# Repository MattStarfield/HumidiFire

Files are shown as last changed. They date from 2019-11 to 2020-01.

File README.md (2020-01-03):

# HumidiFire
A water vapor based fireplace simulator



### Table of Contents
* [Documentation](#Documentation)
* [Hardware](#Hardware)
* [Firmware](#Firmware)
* [Software](#Software)
---

## Documentation

## Hardware
* [Bill of Materials](https://docs.google.com/spreadsheets/d/1JZTtaZDqRExDhAQ4nWuzvwM8wr-2eBfdn1ZWpzmeVy4/edit#gid=0)

## Firmware

## Software

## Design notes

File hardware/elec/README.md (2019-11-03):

### Hardware > Electrical Design
Contains PCB and electronics design files including:

Eagle CAD Project files:
- [ ] Schematic `.sch`
- [ ] PCB Layout `.brd`
- [ ] Library Components `.lbr`
- [ ] Eagle Project File `eagle.epf`

Exported files:
- [ ] Schematic PDF `.pdf`
- [ ] PCB image Render `.png`
- [ ] Gerber files `.zip`

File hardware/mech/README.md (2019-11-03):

### Hardware > Mechanical Design
Contains 2D, 3D CAD and mechanical design files including:

 Adobe Illustrator files:
- [ ] Laser Cut & Engrave files `.ai`

Fusion 360 files:
- [ ]

Exported files:
- [ ] 2D Laser PDF `.pdf`
- [ ] PCB Dimension Outline `.dxf`

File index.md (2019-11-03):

# Project Site
A brief description of the project's function and purpose

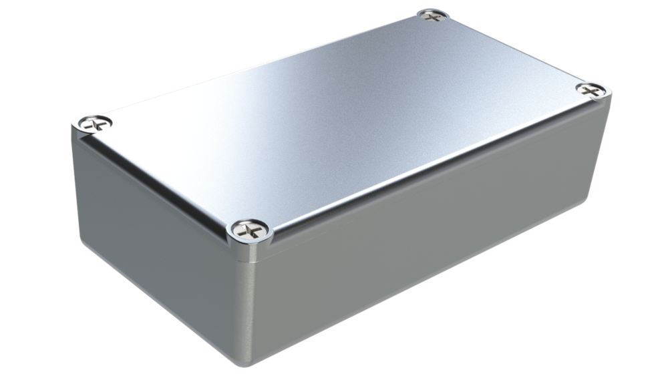
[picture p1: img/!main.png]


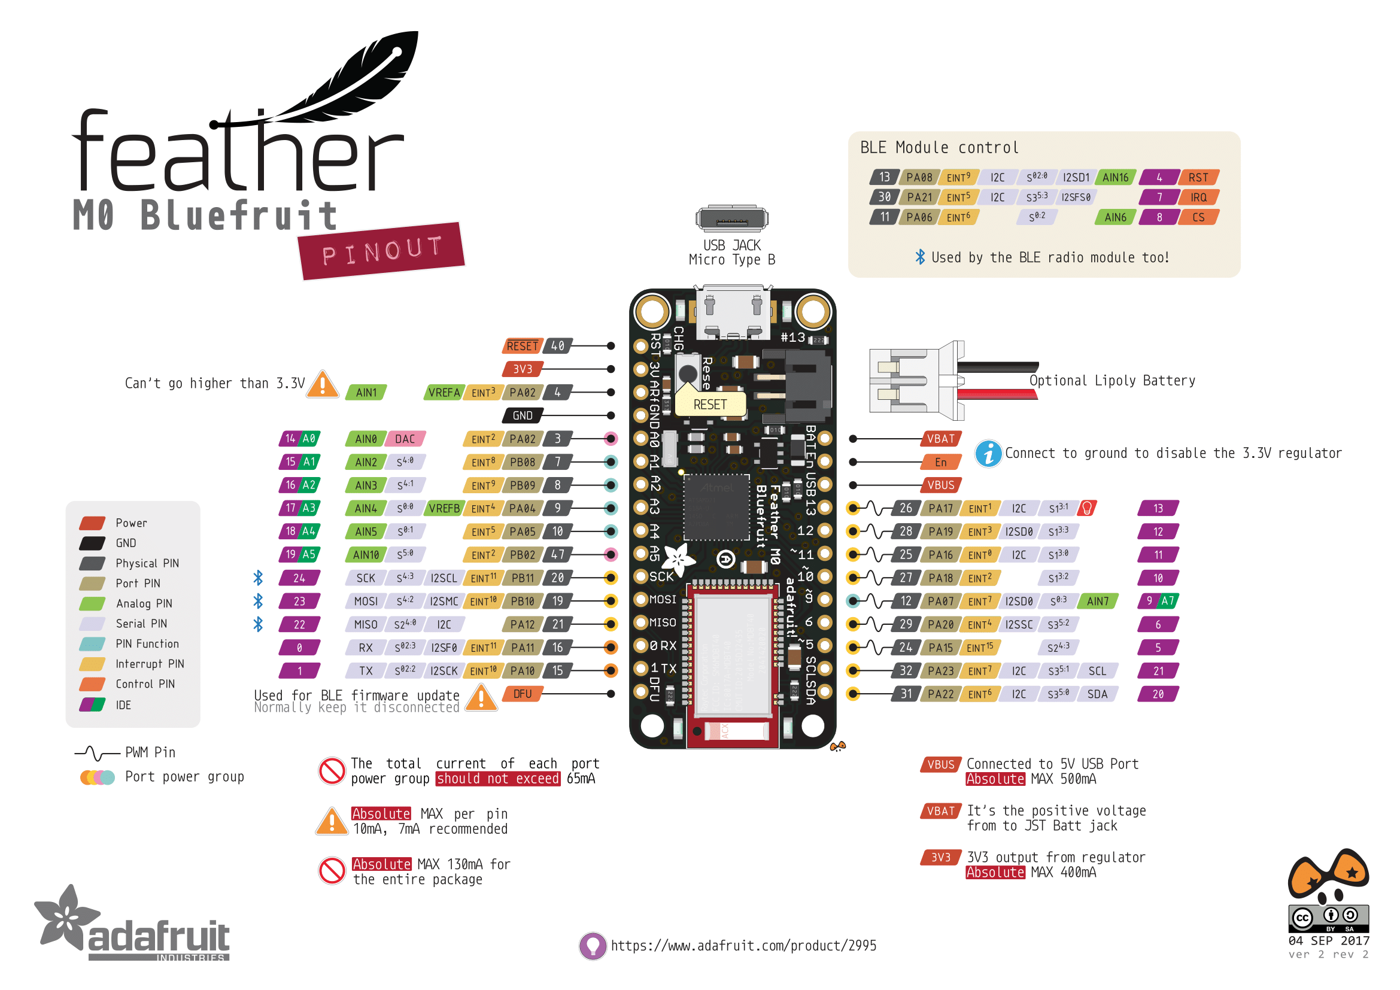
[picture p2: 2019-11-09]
img/feather-m0-pinout.png

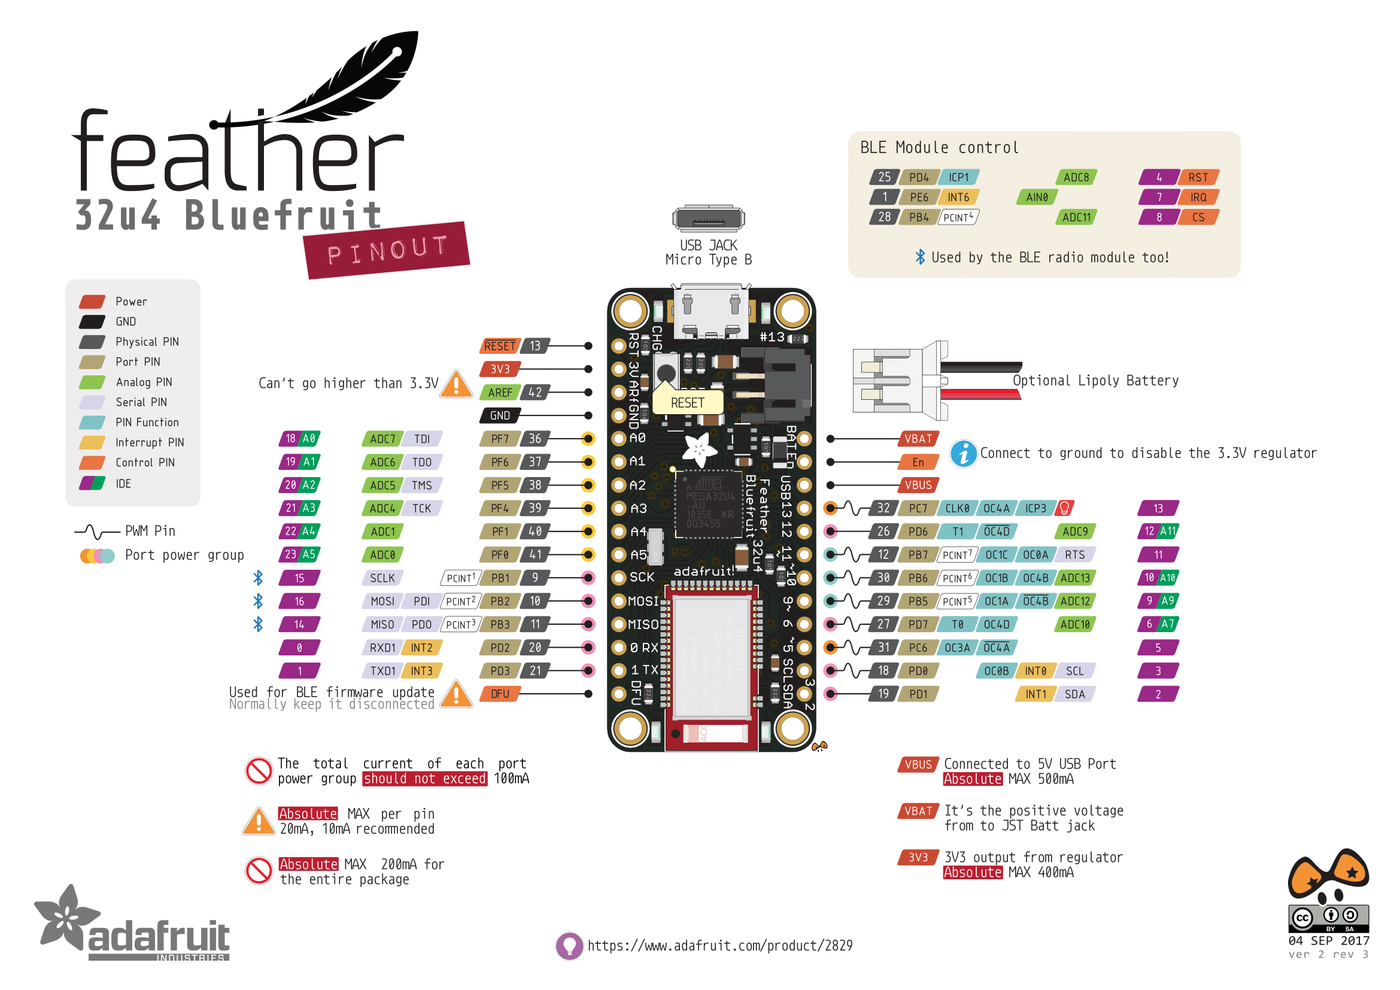
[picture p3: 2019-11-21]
img/feather-32u4-pinout.png

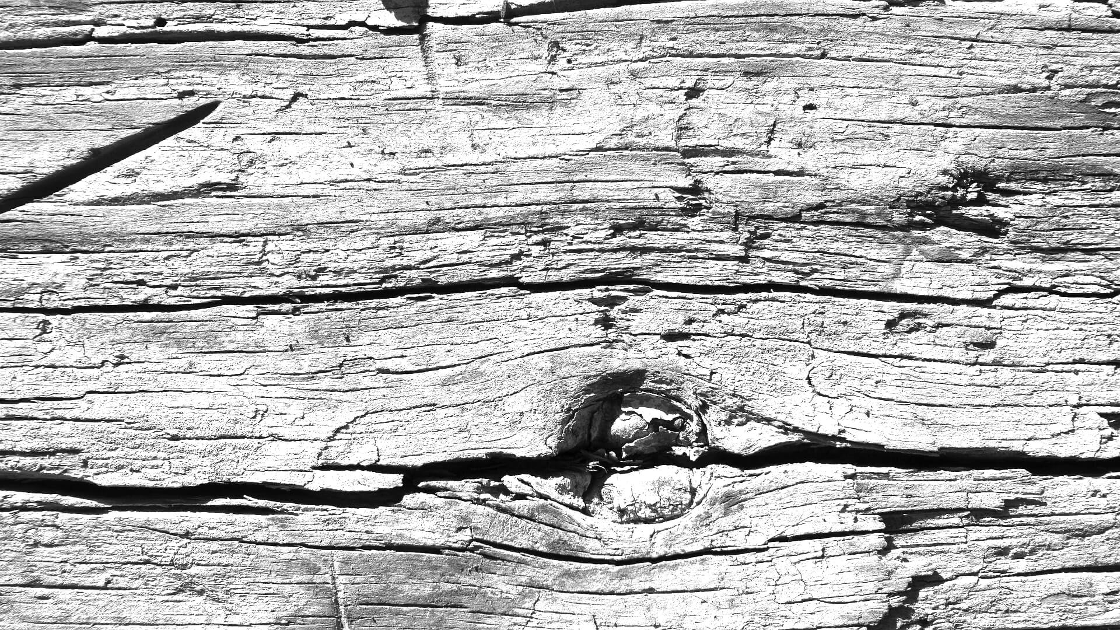
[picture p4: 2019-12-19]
hardware/mech/woodgrain-texture9.jpg

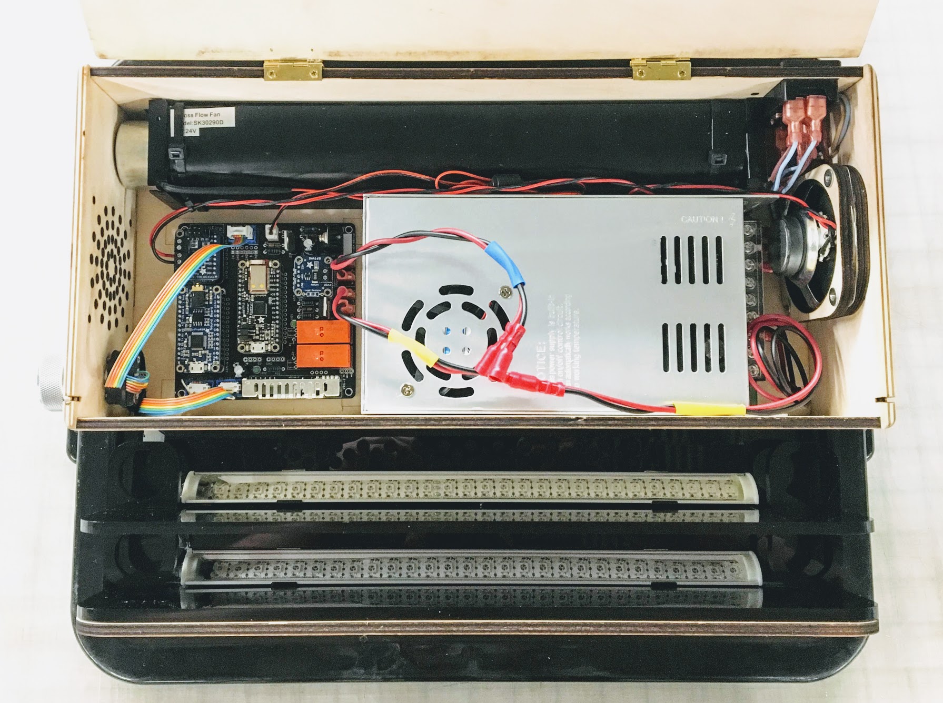
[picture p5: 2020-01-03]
img/hw07.jpg

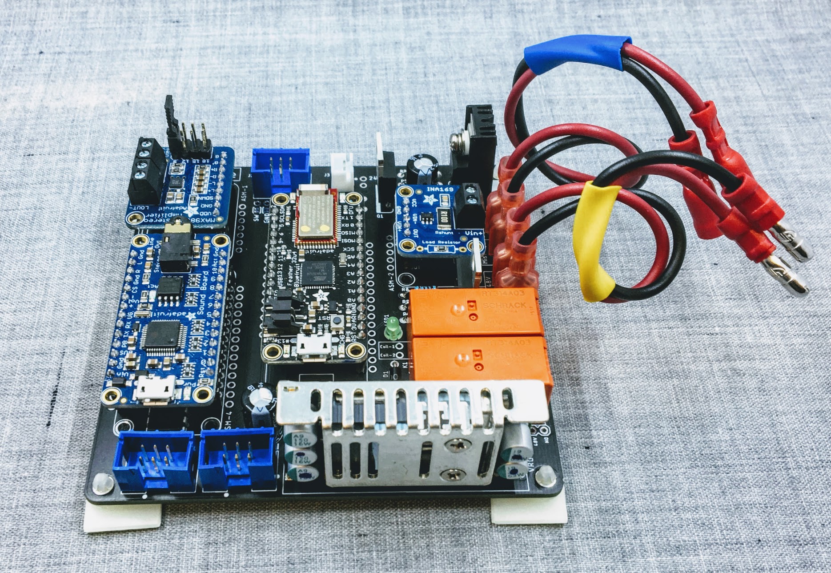
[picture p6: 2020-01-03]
img/pcb04.jpg

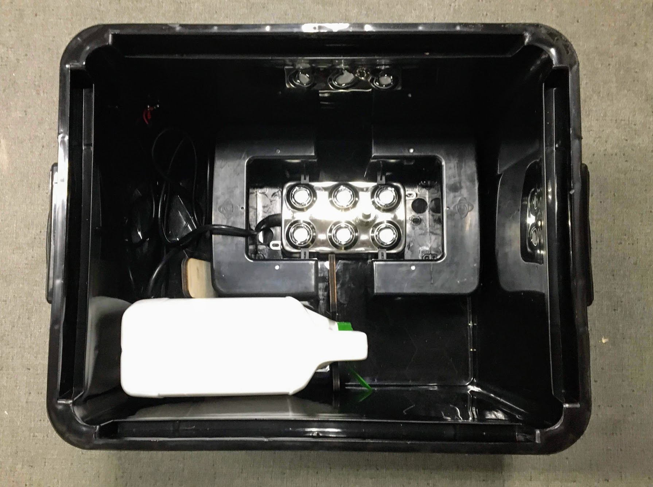
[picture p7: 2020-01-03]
img/hw08.jpg

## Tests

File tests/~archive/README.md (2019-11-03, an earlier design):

### Archive
Contains files that are no longer necessary in the formal project, but may be useful to keep for future reference.

---
_Note: Keep this `README.md` file in place to ensure this folder is included in the Git project structure when the folder is empty_

_Note: `~` is used to place folder at the bottom of file system sorting order_

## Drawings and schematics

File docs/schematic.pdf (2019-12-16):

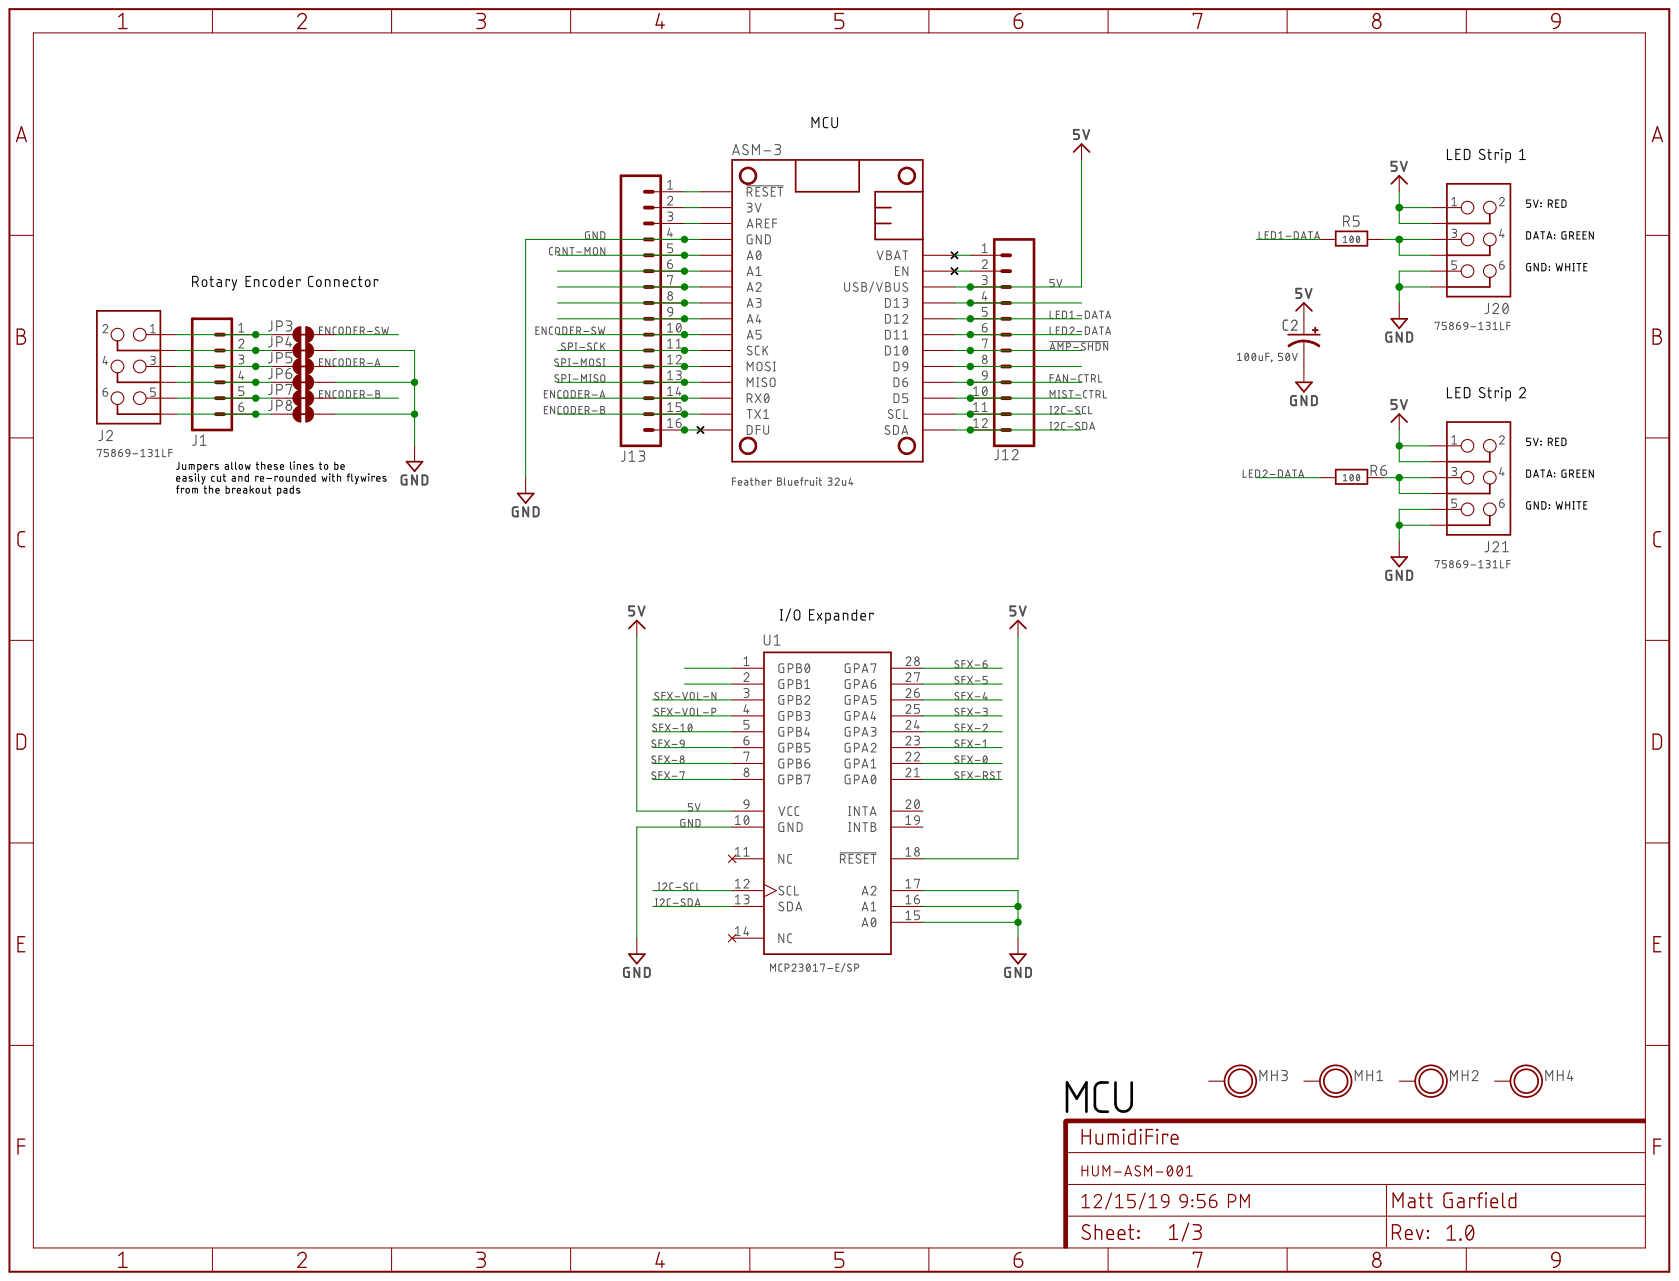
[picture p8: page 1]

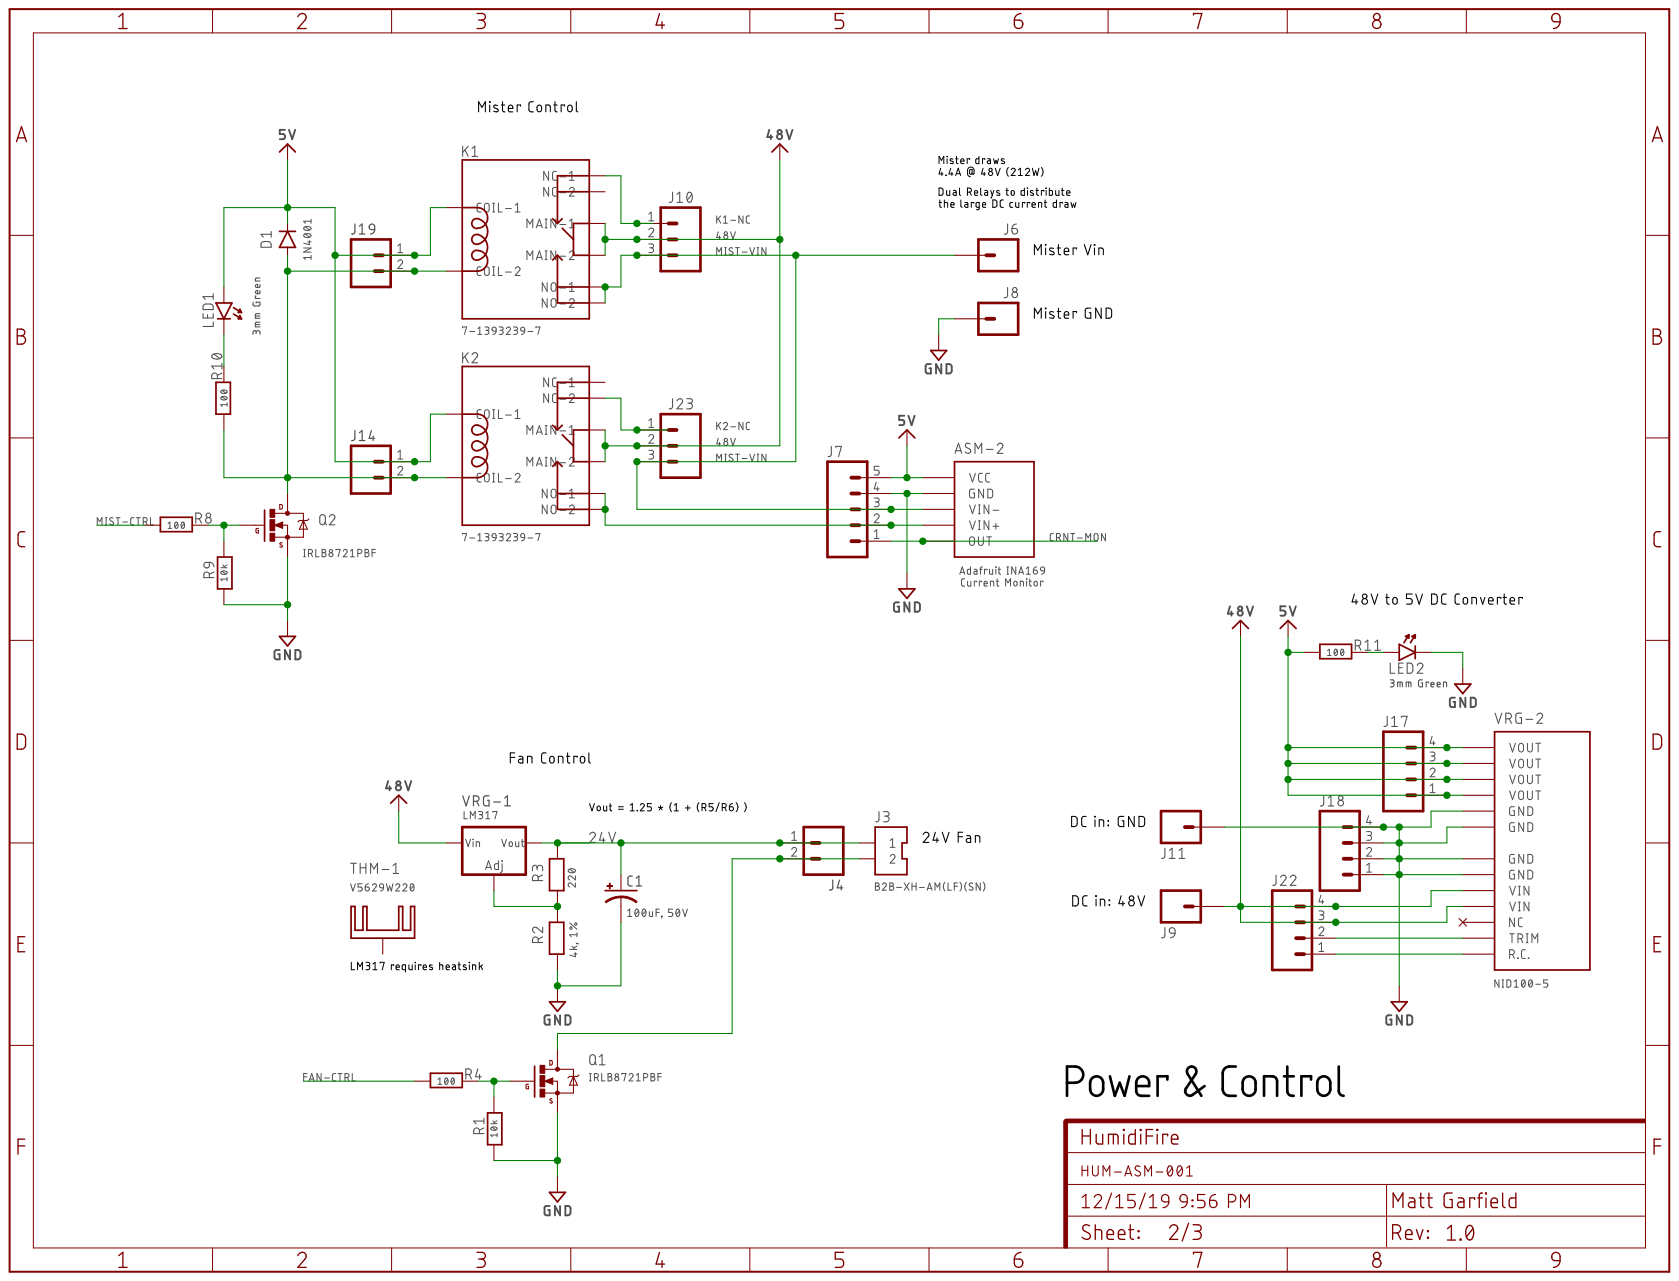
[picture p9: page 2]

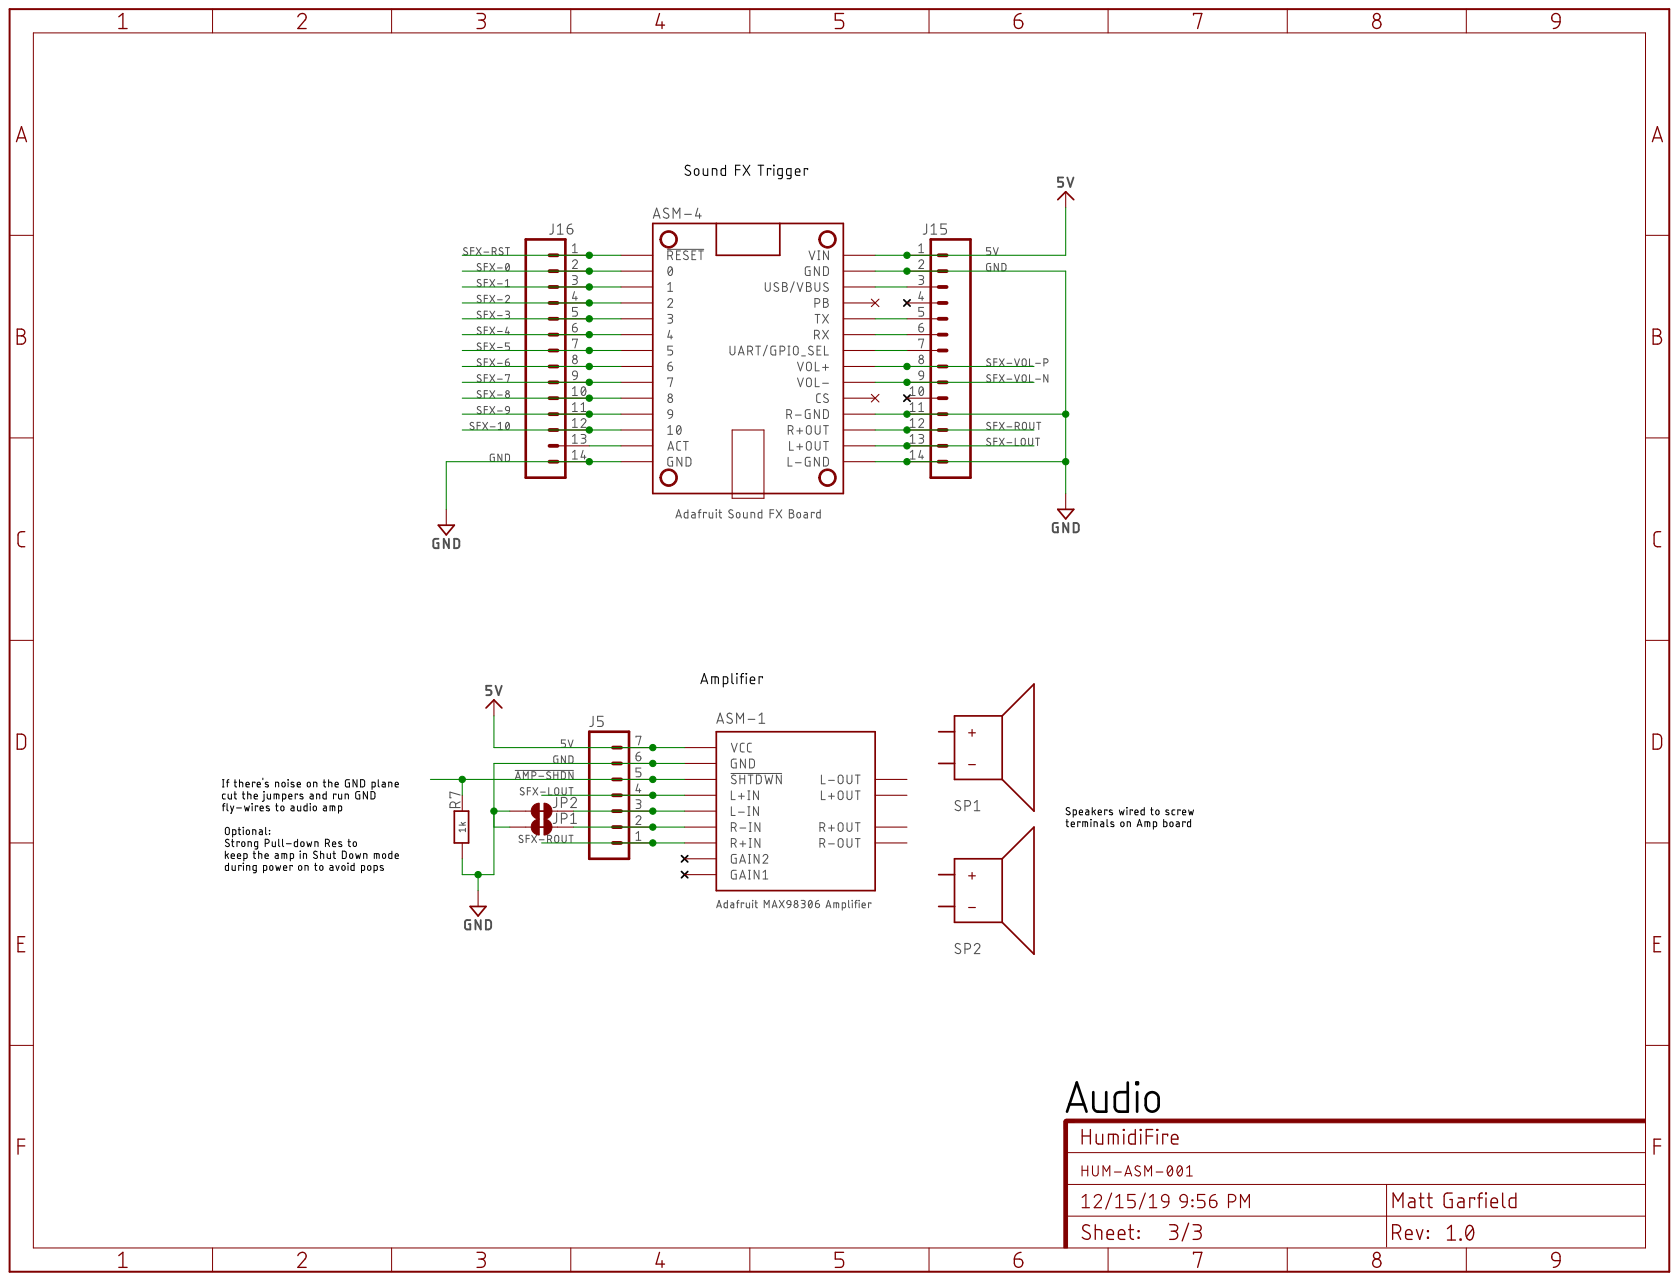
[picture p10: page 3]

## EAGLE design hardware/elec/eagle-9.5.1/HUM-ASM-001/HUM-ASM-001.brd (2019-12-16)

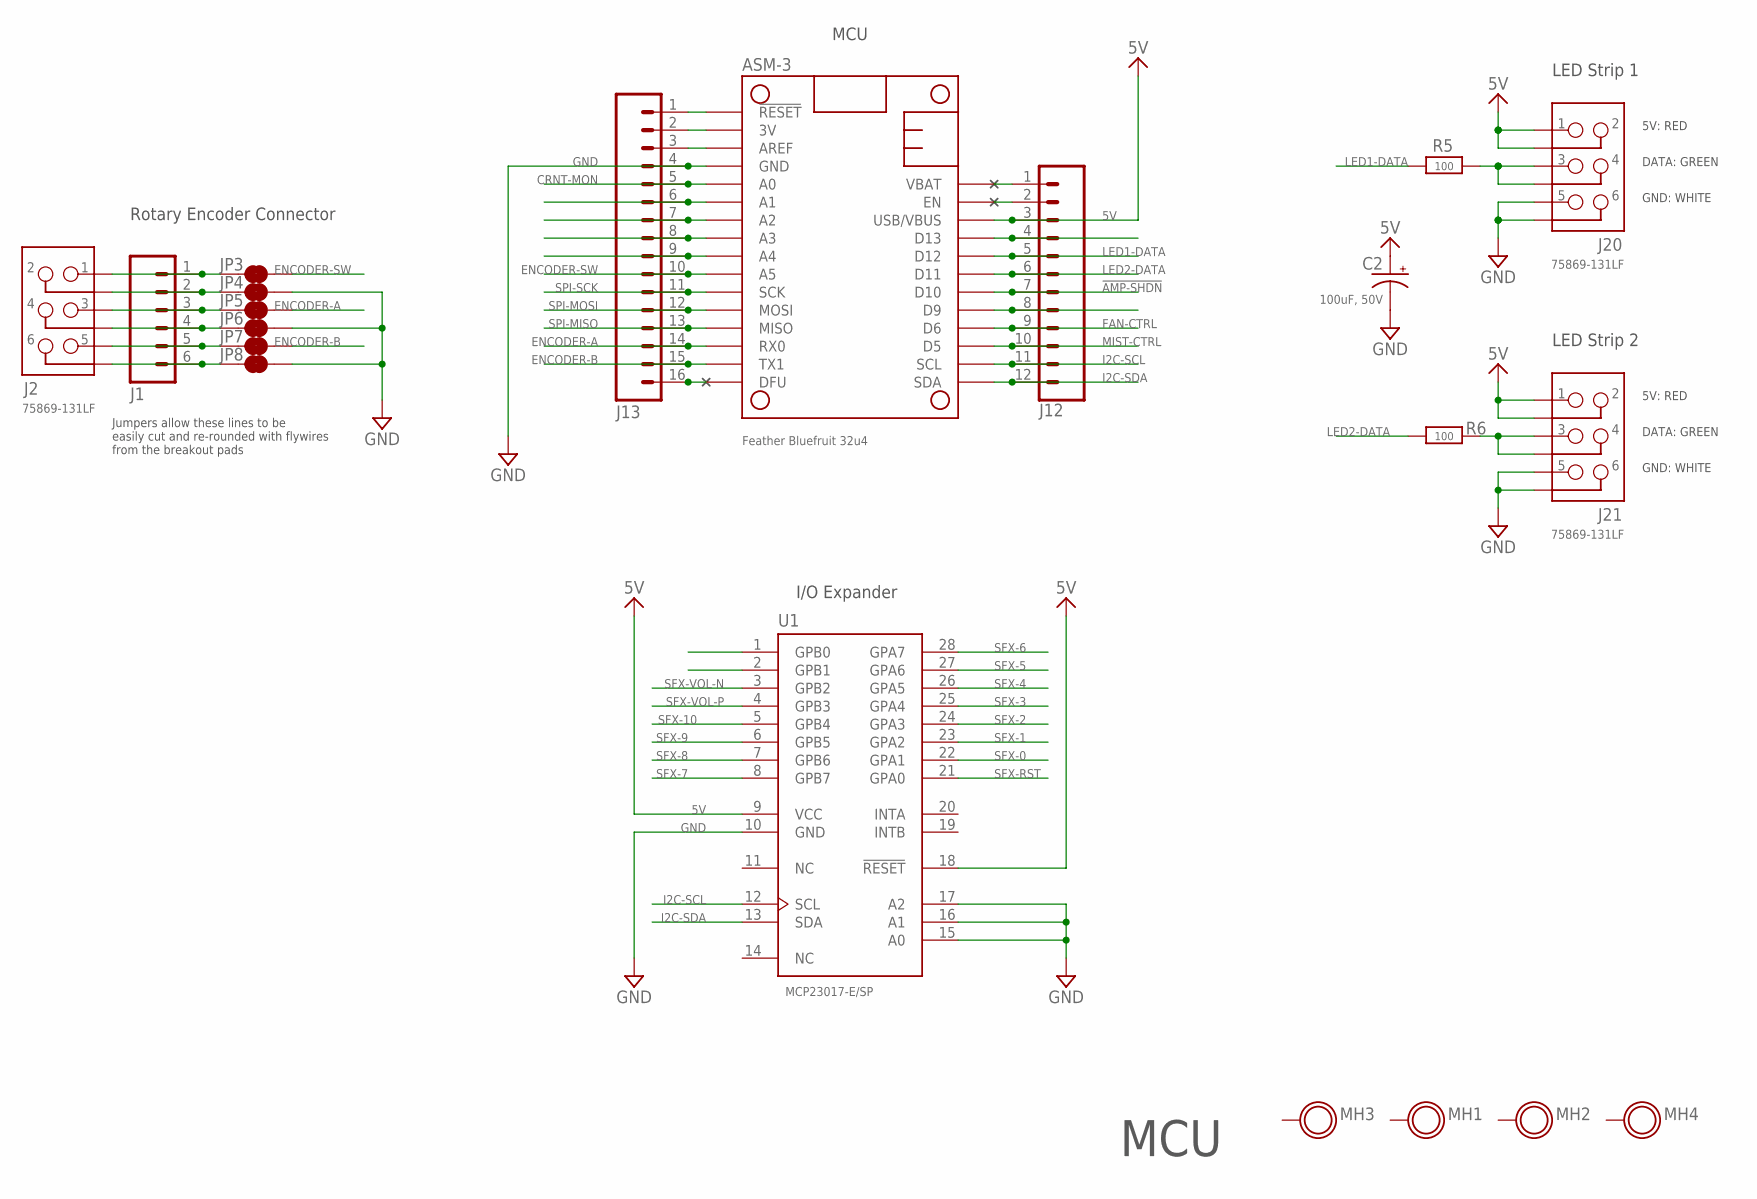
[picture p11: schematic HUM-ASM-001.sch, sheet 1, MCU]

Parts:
ASM-3: Feather Bluefruit 32u4; ASM_ADAFRUIT_FEATHER_BLUEFRUIT
C2: 100uF, 50V; CAP_E-035X080
J1: CON_HEADER_1X6NO_SILK_FEMALE_PTH; 1X06_NO_SILK
J2, J20, J21: 75869-131LF; 2X3-SHROUDED
J12: CON_HEADER_1X12_NO_SILK; 1X12_NO_SILK
J13: CON_HEADER_1X16-1X16_NO_SILK; 1X16_NO_SILK
JP3, JP4, JP5, JP6, JP7, JP8: CON_JUMPER_PAD-2-NC_BY_TRACE; PAD-JUMPER-2-NC_BY_TRACE_YES_SILK
MH1, MH2, MH3, MH4: PCB_MOUNTING-HOLE_IN_PLATED; TOOLING_HOLE_0.125_IN_HORSESHOE
R5, R6: 100; AXIAL-0.4
U1: MCP23017-E/SP; DIP787W45P254L3556H508Q28

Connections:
3V: ASM-3.3V3 (3V), J13.2
5V: ASM-3.USB/VBUS, C2.+, J12.3, J20.1, J20.2, J21.1, J21.2, U1.9 (VCC), U1.18 (!RESET); also elsewhere on the board
!AMP-SHDN: ASM-3.D10, J12.7; also elsewhere on the board
CRNT-MON: ASM-3.A0, J13.5; also elsewhere on the board
DFU: ASM-3.DFU, J13.16
ENCODER-A: ASM-3.RX0, J13.14, JP5.1
ENCODER-B: ASM-3.TX1, J13.15, JP7.1
ENCODER-SW: ASM-3.A5, J13.10, JP3.1
FAN-CTRL: ASM-3.D6, J12.9; also elsewhere on the board
GND: ASM-3.GND@4 (GND), C2.-, J13.4, J20.5, J20.6, J21.5, J21.6, JP4.1, JP6.1, JP8.1, U1.10 (GND), U1.15 (A0), U1.16 (A1), U1.17 (A2); also elsewhere on the board
I2C-SCL: ASM-3.SCL, J12.11, U1.12 (SCL)
I2C-SDA: ASM-3.SDA, J12.12, U1.13 (SDA)
LED1-DATA: ASM-3.D12, J12.5, R5.P$2 (P2)
LED2-DATA: ASM-3.D11, J12.6, R6.P$1 (P1)
MIST-CTRL: ASM-3.D5, J12.10; also elsewhere on the board
unnamed: ASM-3.!RESET, J13.1
unnamed: ASM-3.AREF, J13.3
unnamed: ASM-3.A1, J13.6
unnamed: ASM-3.A2, J13.7
unnamed: ASM-3.A3, J13.8
unnamed: ASM-3.A4, J13.9
unnamed: J20.3, J20.4, R5.P$1 (P1)
unnamed: J1.1, J2.1, JP3.2
unnamed: ASM-3.D9, J12.8
unnamed: J1.2, J2.2, JP4.2
unnamed: J1.3, J2.3, JP5.2
unnamed: ASM-3.D13, J12.4
unnamed: ASM-3.EN, J12.2
unnamed: J1.4, J2.4, JP6.2
unnamed: J1.5, J2.5, JP7.2
unnamed: J1.6, J2.6, JP8.2
unnamed: J21.3, J21.4, R6.P$2 (P2)
SFX-0: U1.22 (GPA1); also elsewhere on the board
SFX-1: U1.23 (GPA2); also elsewhere on the board
SFX-2: U1.24 (GPA3); also elsewhere on the board
SFX-3: U1.25 (GPA4); also elsewhere on the board
SFX-4: U1.26 (GPA5); also elsewhere on the board
SFX-5: U1.27 (GPA6); also elsewhere on the board
SFX-6: U1.28 (GPA7); also elsewhere on the board
SFX-7: U1.8 (GPB7); also elsewhere on the board
SFX-8: U1.7 (GPB6); also elsewhere on the board
SFX-9: U1.6 (GPB5); also elsewhere on the board
SFX-10: U1.5 (GPB4); also elsewhere on the board
SFX-RST: U1.21 (GPA0); also elsewhere on the board
SFX-VOL-N: U1.3 (GPB2); also elsewhere on the board
SFX-VOL-P: U1.4 (GPB3); also elsewhere on the board
SPI-MISO: ASM-3.MISO, J13.13
SPI-MOSI: ASM-3.MOSI, J13.12
SPI-SCK: ASM-3.SCK, J13.11
VBAT: ASM-3.VBAT, J12.1

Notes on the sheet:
MCU
I/O Expander
Rotary Encoder Connector
Jumpers allow these lines to be easily cut and re-rounded with flywires from the breakout pads
5V: RED
DATA: GREEN
GND: WHITE
LED Strip 1
LED Strip 2

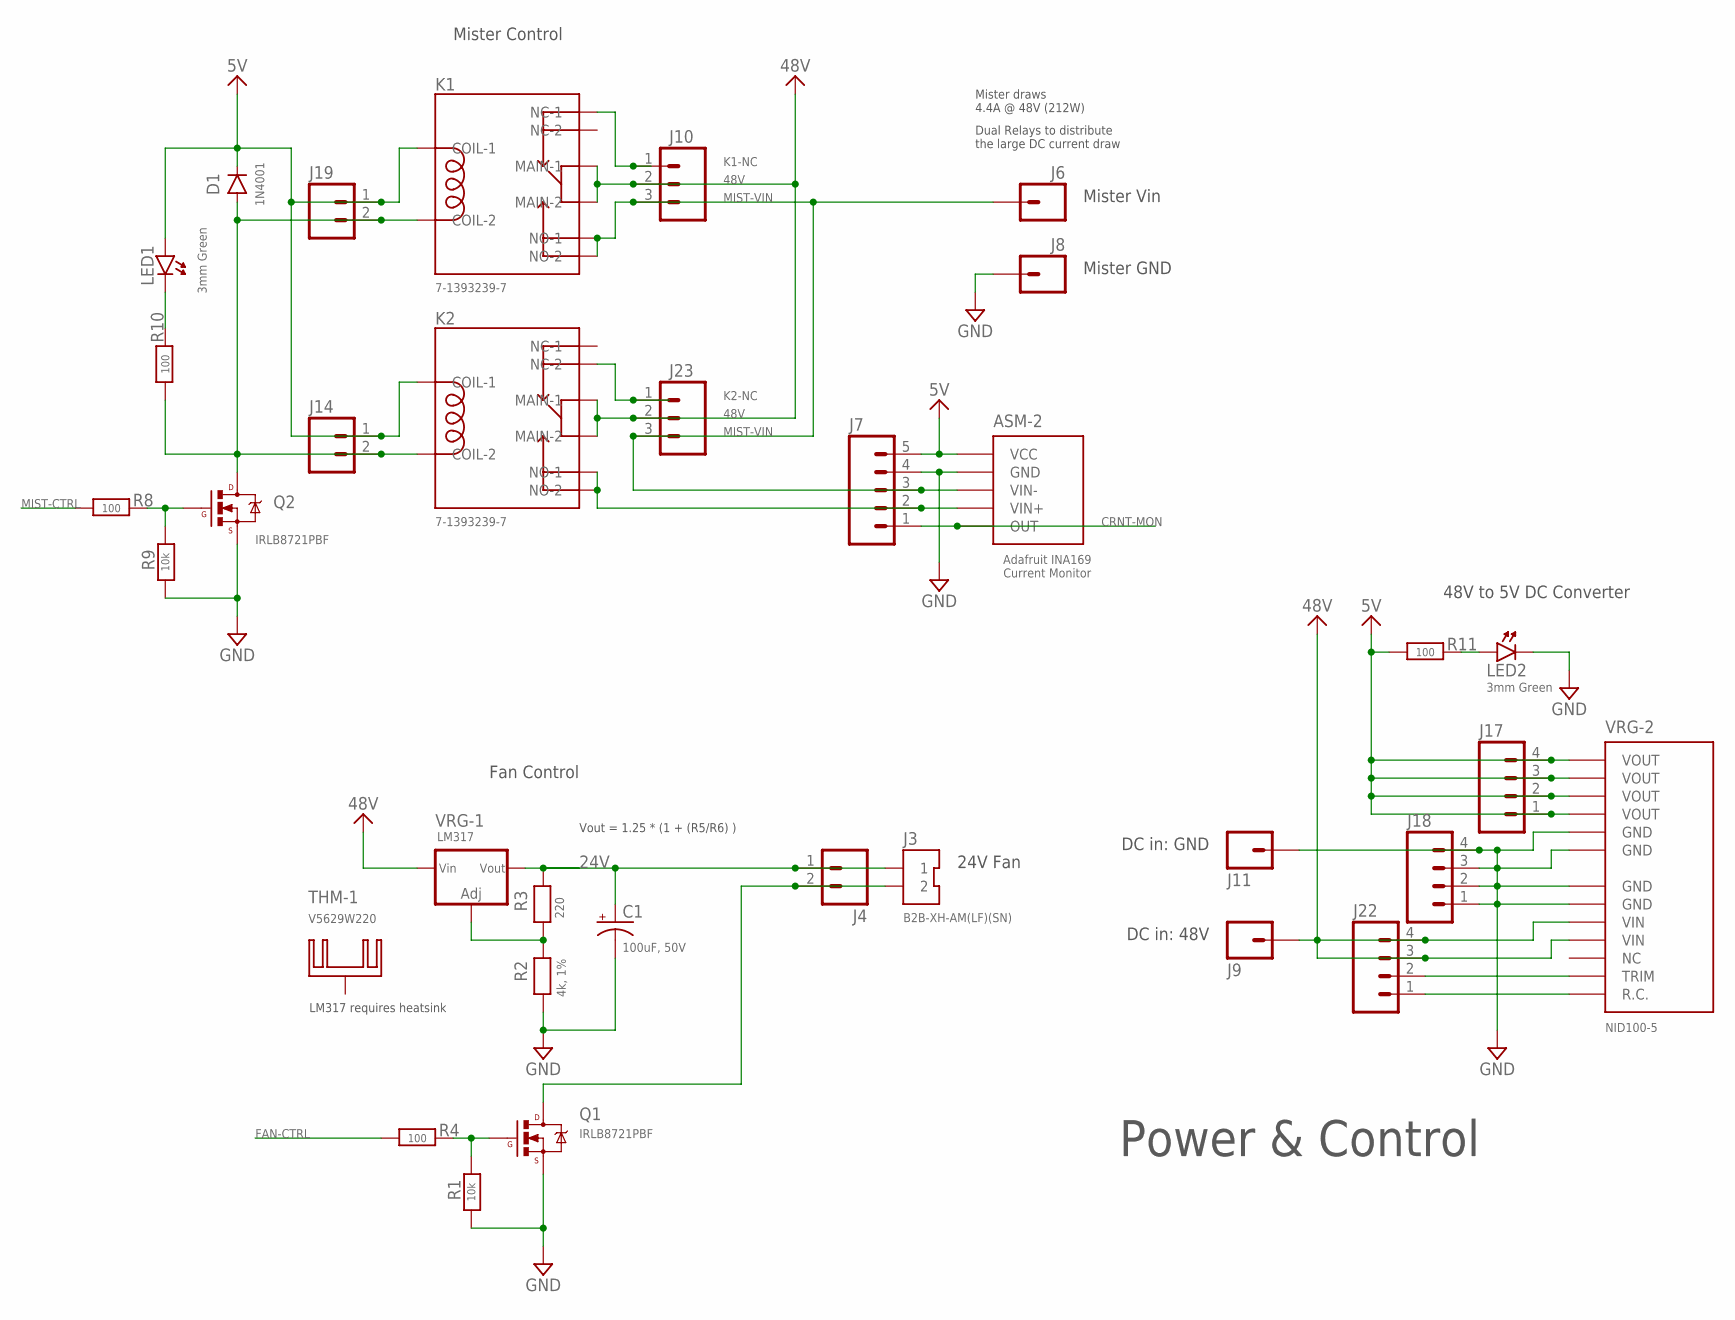
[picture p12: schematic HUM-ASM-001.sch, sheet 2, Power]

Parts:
ASM-2: ASM_ADAFRUIT_INA169; ASM_ADAFRUIT_INA169_MOUNTING_HOLES
C1: 100uF, 50V; CAP_E-035X080
D1: 1N4001; DIODE-1N4001
J3: B2B-XH-AM(LF)(SN); JST-2-PTH-VERT_XH
J4, J14, J19: CON_HEADER_1X21X02_NO_SILK; 1X02_NO_SILK
J6, J8, J9, J11: CON_HEADER_1X1-QC_TAB_121786-1; TE_1217861-1
J7: CON_HEADER_1X5NO_SILK; 1X05_NO_SILK
J10, J23: CON_HEADER_1X3PTH; 1X03
J17, J18: CON_HEADER_1X4PTH; 1X04
J22: CON_HEADER_1X4NO_SILK_ALL_ROUND; 1X04_NO_SILK_ALL_ROUND
K1, K2: 7-1393239-7; RELAY_TE_7-1393239-7
LED1, LED2: 3mm Green; LED3MM
Q1, Q2: IRLB8721PBF; TO-220-VERTICAL
R1, R9: 10k; AXIAL-0.4
R2: 4k, 1%; AXIAL-0.4
R3: 220; AXIAL-0.4
R4, R8, R10, R11: 100; AXIAL-0.4
THM-1: V5629W220; SK95-2M3
VRG-1: LM317; TO-220-VERTICAL
VRG-2: NID100-5; VRG_NID100-X

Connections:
5V: ASM-2.1 (VCC), D1.C, J7.5, J14.1, J17.1, J17.2, J17.3, J17.4, J19.1, K1.COIL-1, K2.COIL-1, LED1.A, R11.P$1 (P1), VRG-2.P$1 (VOUT), VRG-2.P$2 (VOUT), VRG-2.P$3 (VOUT), VRG-2.P$4 (VOUT); also elsewhere on the board
24V: C1.+, J3.1, J4.1, R3.P$2 (P2), VRG-1.P2 (VOUT)
48V: J9.1, J9.2, J10.2, J22.3, J22.4, J23.2, K1.MAIN-1, K1.MAIN-2, K2.MAIN-1, K2.MAIN-2, VRG-1.P3 (VIN), VRG-2.P$9 (VIN), VRG-2.P$10 (VIN)
ADJ: R2.P$2 (P2), R3.P$1 (P1), VRG-1.P1 (ADJ)
CRNT-MON: ASM-2.5 (OUT), J7.1; also elsewhere on the board
FAN-CTRL: R4.P$1 (P1); also elsewhere on the board
GND: ASM-2.2 (GND), C1.-, J7.4, J8.1, J8.2, J11.1, J11.2, J18.1, J18.2, J18.3, J18.4, LED2.K (C), Q1.P3 (S), Q2.P3 (S), R1.P$2 (P2), R2.P$1 (P1), R9.P$2 (P2), VRG-2.P$5 (GND), VRG-2.P$6 (GND), VRG-2.P$7 (GND), VRG-2.P$8 (GND); also elsewhere on the board
K1-NC: J10.1, K1.NC-1
K2-NC: J23.1, K2.NC-2
MIST-CTRL: R8.P$1 (P1); also elsewhere on the board
MIST-VIN: ASM-2.3 (VIN-), J6.1, J6.2, J7.3, J10.3, J23.3, K1.NO-1, K1.NO-2
unnamed: D1.A, J14.2, J19.2, K1.COIL-2, K2.COIL-2, Q2.P2 (D), R10.P$1 (P1)
unnamed: Q2.P1 (G), R8.P$2 (P2), R9.P$1 (P1)
unnamed: J3.2, J4.2, Q1.P2 (D)
unnamed: LED1.K (C), R10.P$2 (P2)
unnamed: ASM-2.4 (VIN+), J7.2, K2.NO-1, K2.NO-2
unnamed: Q1.P1 (G), R1.P$1 (P1), R4.P$2 (P2)
unnamed: LED2.A, R11.P$2 (P2)
unnamed: J22.1, VRG-2.P$13 (R.C.)
unnamed: J22.2, VRG-2.P$12 (TRIM)

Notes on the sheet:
Power & Control
Mister draws 4.4A @ 48V (212W)
Dual Relays to distribute the large DC current draw
48V to 5V DC Converter
Mister Control
Vout = 1.25 * (1 + (R5/R6) )
24V Fan
LM317 requires heatsink
Fan Control
DC in: GND
DC in: 48V
Mister Vin
Mister GND

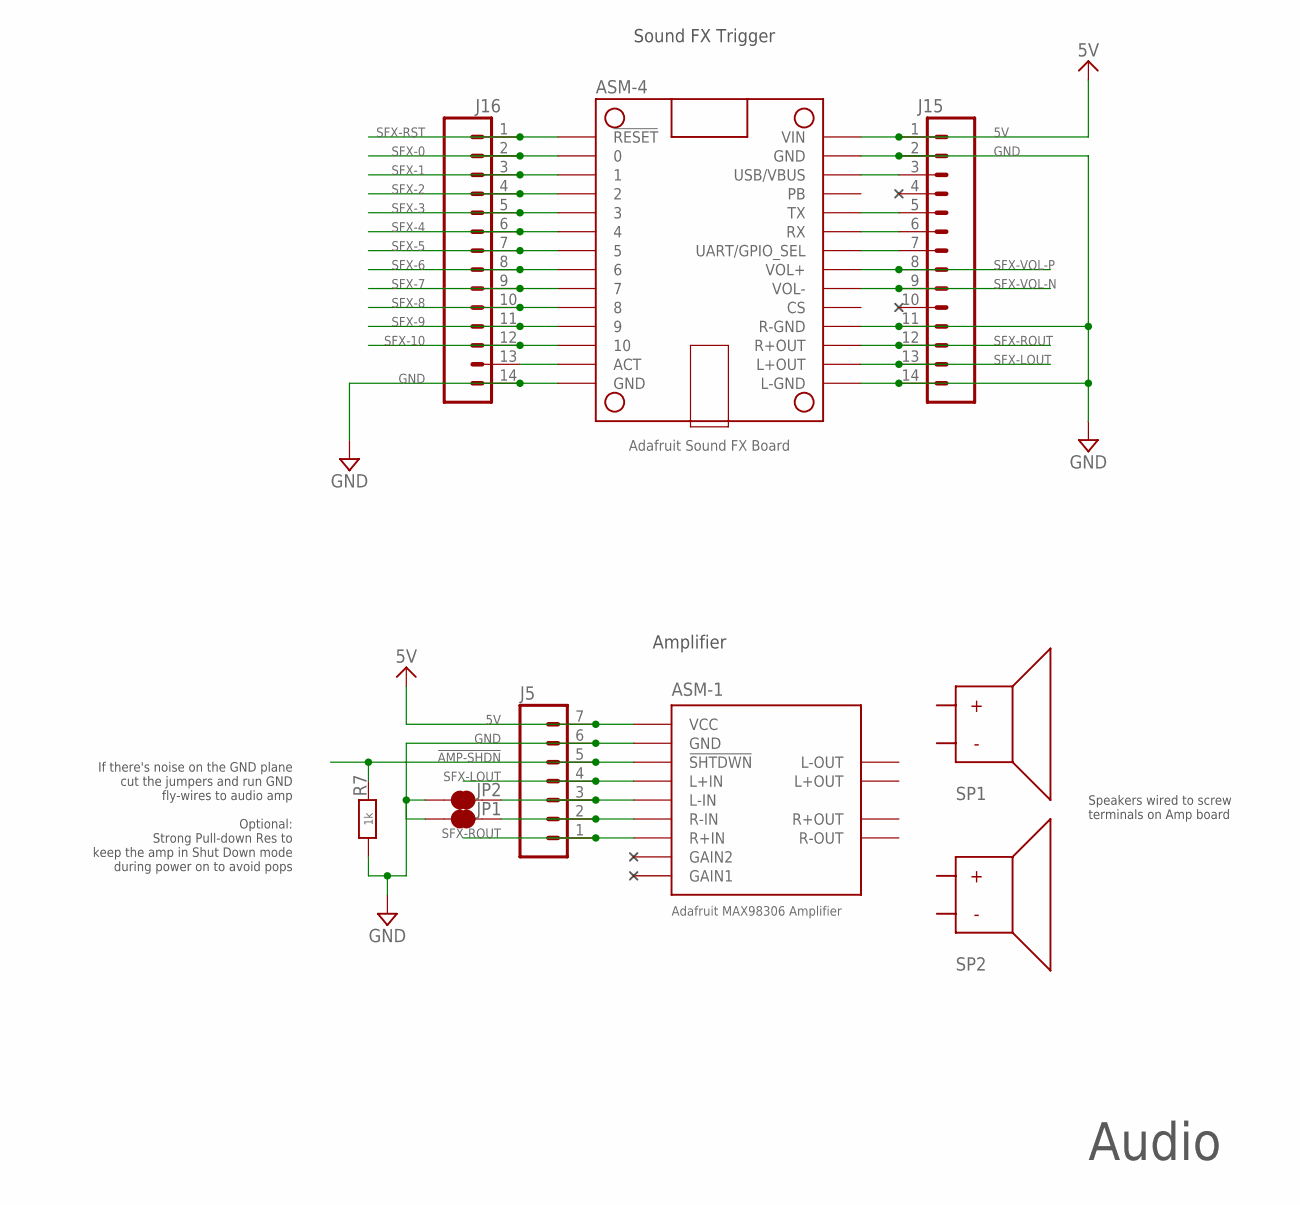
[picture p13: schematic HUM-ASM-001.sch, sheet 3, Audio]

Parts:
ASM-1: ASM_ADAFRUIT_MAX98306_AMP; ASM_ADAFRUIT_MAX98306_AMP_MOUNTING_HOLES
ASM-4: ASM_ADAFRUIT_SOUND_FX_BOARD
J5: CON_HEADER_1X7NO_SILK; 1X07_NO_SILK
J15, J16: CON_HEADER_1X14; 1X14_NO_SILK
JP1, JP2: CON_JUMPER_PAD-2-NC_BY_TRACE; PAD-JUMPER-2-NC_BY_TRACE_YES_SILK
R7: 1k; AXIAL-0.4

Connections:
5V: ASM-1.1 (VCC), ASM-4.28 (VIN), J5.7, J15.1; also elsewhere on the board
!AMP-SHDN: ASM-1.3 (!SHTDWN), J5.5, R7.P$2 (P2); also elsewhere on the board
GND: ASM-1.2 (GND), ASM-4.14 (GND), ASM-4.15 (L-GND), ASM-4.18 (R-GND), ASM-4.27 (GND), J5.6, J15.2, J15.11, J15.14, J16.14, JP1.1, JP2.1, R7.P$1 (P1); also elsewhere on the board
unnamed: ASM-1.5 (L-IN), J5.3, JP2.2
unnamed: ASM-1.6 (R-IN), J5.2, JP1.2
unnamed: ASM-4.13 (ACT), J16.13
unnamed: ASM-4.24 (TX), J15.5
unnamed: ASM-4.23 (RX), J15.6
unnamed: ASM-4.22 (UART/GPIO_SEL), J15.7
SFX-0: ASM-4.2 (0), J16.2; also elsewhere on the board
SFX-1: ASM-4.3 (1), J16.3; also elsewhere on the board
SFX-2: ASM-4.4 (2), J16.4; also elsewhere on the board
SFX-3: ASM-4.5 (3), J16.5; also elsewhere on the board
SFX-4: ASM-4.6 (4), J16.6; also elsewhere on the board
SFX-5: ASM-4.7 (5), J16.7; also elsewhere on the board
SFX-6: ASM-4.8 (6), J16.8; also elsewhere on the board
SFX-7: ASM-4.9 (7), J16.9; also elsewhere on the board
SFX-8: ASM-4.10 (8), J16.10; also elsewhere on the board
SFX-9: ASM-4.11 (9), J16.11; also elsewhere on the board
SFX-10: ASM-4.12 (10), J16.12; also elsewhere on the board
SFX-LOUT: ASM-1.4 (L+IN), ASM-4.16 (L+OUT), J5.4, J15.13
SFX-ROUT: ASM-1.7 (R+IN), ASM-4.17 (R+OUT), J5.1, J15.12
SFX-RST: ASM-4.1 (!RESET), J16.1; also elsewhere on the board
SFX-VOL-N: ASM-4.20 (VOL-), J15.9; also elsewhere on the board
SFX-VOL-P: ASM-4.21 (VOL+), J15.8; also elsewhere on the board
USB/VBUS: ASM-4.26 (USB/VBUS), J15.3

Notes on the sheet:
Audio
If there's noise on the GND plane cut the jumpers and run GND fly-wires to audio amp
Optional: Strong Pull-down Res to keep the amp in Shut Down mode during power on to avoid pops
Speakers wired to screw terminals on Amp board
Amplifier
Sound FX Trigger

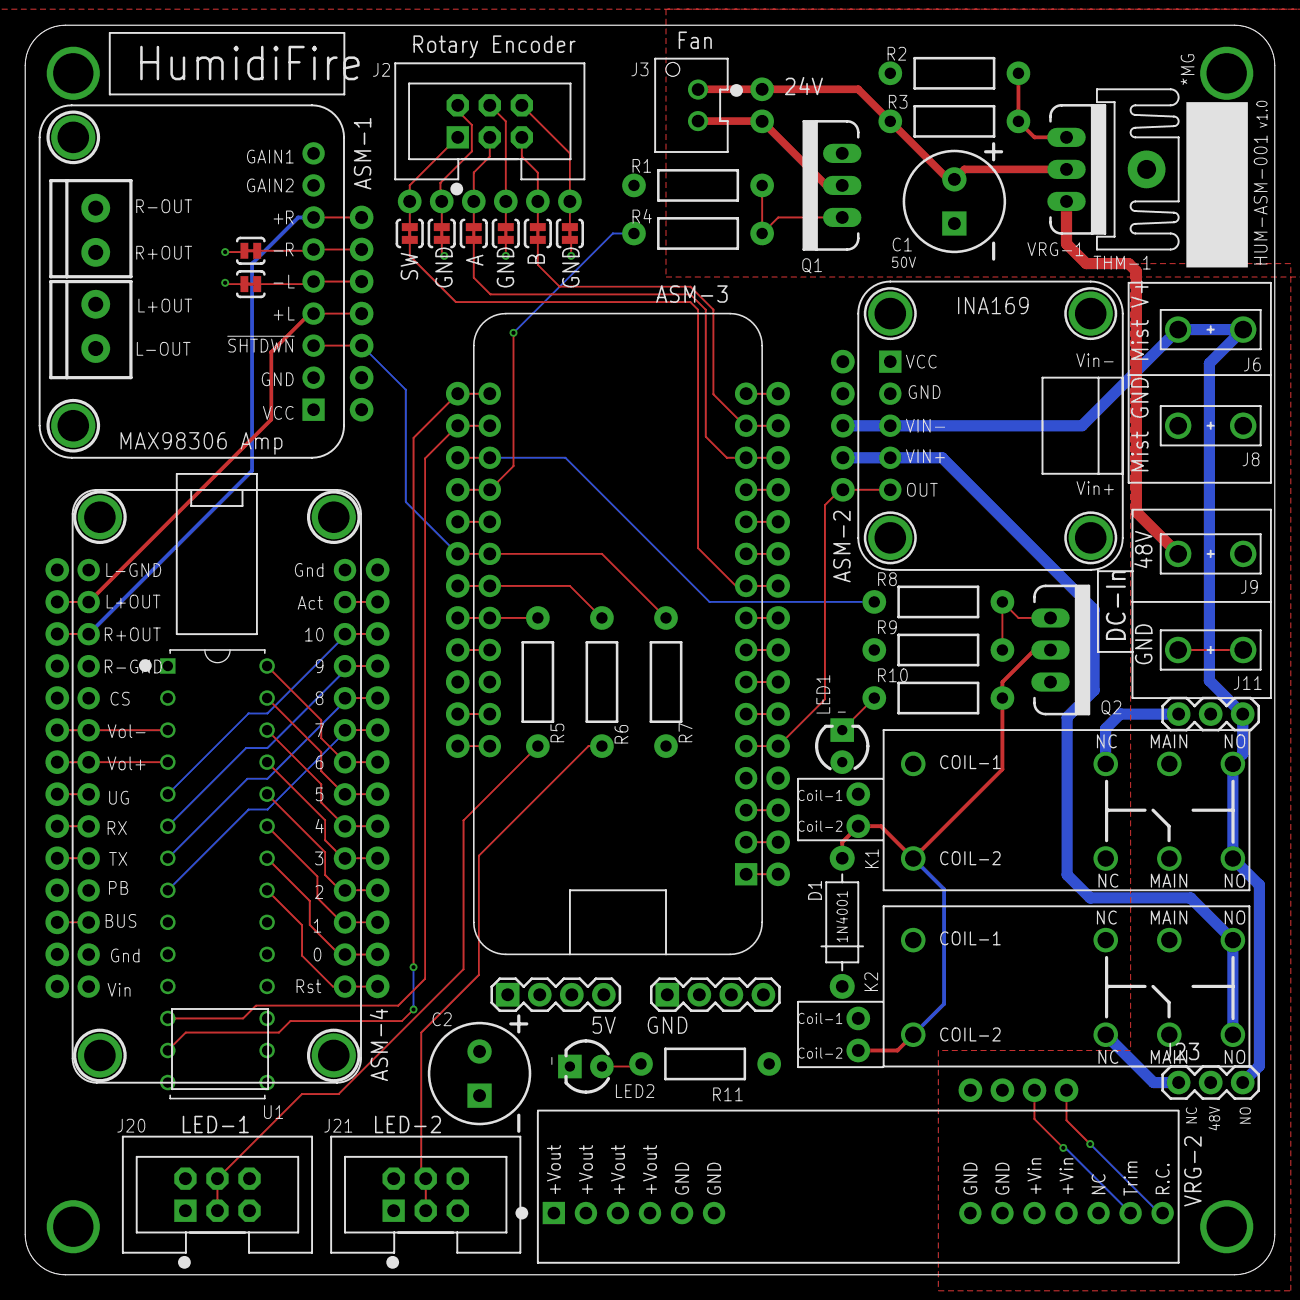
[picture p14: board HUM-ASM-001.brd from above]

Board: 2 copper layers, 99.1 x 99.1 mm, 63 parts (0 on the bottom side), 74 nets.

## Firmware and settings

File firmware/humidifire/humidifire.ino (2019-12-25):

/* 
 *  HumidiFire Firmware
 *  by Matt Garfield

 * TODO:
 * ----------
 * 
 * - add EEPROM ability to store array settings[mode][fanPwm, mistPwm]
 * 
 * - make rotary encoder fan speed control more fluid / intuitive
 *    - percieved fan speed is not linaerly proportional to PWM duty cycle
 *    - most variation is in 0 - 127 range
 *    - lookup table approach? maybe just 4 speed settings?
 *    
 * - add current monitoring of mister to stop mode & alert when water is low
 * 
 * CHANGELOG:
 * ----------
 * 12/24/2019
 * - Running 2 strips of LEDs
 * - Changed to FSM model
 * 
 * 12/23/2019
 * - Updated Pinout to reflect PCB wiring
 * - Modifications for 2 strips of LEDs (pixels_1 and pixels_2)
 * 
 * 12/4/2019
 * - Added Mister Relay control to Pin 5
 * 
 * 11/29/2019
 * - Added Current Monitor 
 * 
 * 11/27/2019
 * - Upgraded to MCP23017 I2C 16 I/O Expander Library
 * 
 * 11/20/2019
 * - Updated NUM_PIXELS to 31
 * - Moved to Feather 32u4 
 *     - Feather M0 has NO EEPROM memory!!
 *     - Feather M0 isn't compatible with <Adafruit_MCP23008.h> I2C Expander library
 * 
 * 11/16/2019
 * - added I2C expander library for control of SoundFX board
 * 
 * 11/15/2019
 * - added NeoPixel functionality
 * 
 * 11/13/2019
 * - collected and syncronized display updates of BLE & Serial Montior for settings changes at the end of loop() with settingsUpdate flag
 * - added modeToString() function to print mode names
 * - added EasyButton library and functionality
 *  - onPressed
 *  - onPressedFor (held for 1 sec)
 *  - onSequence (2 clicks in 1 sec)
 * 
 * 11/10/2019
 * - Rotary Encoder fan speed control
 * - Bluefruit Connect App fan, mist, and mode control
 * 
 * 11/9/2019
 * - Initial setup
*/

/*=========================================================================*/
// == Debug Set == //
/*=========================================================================*/

  // Controls Verbose "Print" Output to Serial Terminal
  const bool debugSet = false;
  //const bool debugSet = true;
  
/*=========================================================================*/
// == Include Libraries == //
/*=========================================================================*/
  
  // Bluefruit Libraries
  // Library: Adafruit_BluefruitLE_nRF51
  #include <Wire.h>
  //#include <SPI.h>
  
  #include <string.h>
  #include <Arduino.h>
  #include "Adafruit_BLE.h"
  #include "Adafruit_BluefruitLE_SPI.h"
  #include "Adafruit_BluefruitLE_UART.h"
  
  // Config Files
  #include "BluefruitConfig.h"
  //#include "BluefruitSetup.ino"
  
  #include <Encoder.h>                  // http://www.pjrc.com/teensy/td_libs_Encoder.html
  #include <EasyButton.h>               // https://github.com/evert-arias/EasyButton
  #include <Adafruit_NeoPixel.h>        // https://github.com/adafruit/Adafruit_NeoPixel
  //#include <Adafruit_MCP23008.h>        // I2C 8 Expander IC // https://github.com/adafruit/Adafruit-MCP23008-library
  #include <Adafruit_MCP23017.h>        // I2C 16 Expander IC//https://github.com/adafruit/Adafruit-MCP23017-Arduino-Library

  
  #if SOFTWARE_SERIAL_AVAILABLE
    #include <SoftwareSerial.h>
  #endif

/*=========================================================================
    APPLICATION SETTINGS

    FACTORYRESET_ENABLE       Perform a factory reset when running this sketch
   
                              Enabling this will put your Bluefruit LE module
                              in a 'known good' state and clear any config
                              data set in previous sketches or projects, so
                              running this at least once is a good idea.
   
                              When deploying your project, however, you will
                              want to disable factory reset by setting this
                              value to 0.  If you are making changes to your
                              Bluefruit LE device via AT commands, and those
                              changes aren't persisting across resets, this
                              is the reason why.  Factory reset will erase
                              the non-volatile memory where config data is
                              stored, setting it back to factory default
                              values.
       
                              Some sketches that require you to bond to a
                              central device (HID mouse, keyboard, etc.)
                              won't work at all with this feature enabled
                              since the factory reset will clear all of the
                              bonding data stored on the chip, meaning the
                              central device won't be able to reconnect.
    MINIMUM_FIRMWARE_VERSION  Minimum firmware version to have some new features
    MODE_LED_BEHAVIOUR        LED activity, valid options are
                              "DISABLE" or "MODE" or "BLEUART" or
                              "HWUART"  or "SPI"  or "MANUAL"
    -----------------------------------------------------------------------*/
    #define FACTORYRESET_ENABLE         1
    #define MINIMUM_FIRMWARE_VERSION    "0.6.6"
    #define MODE_LED_BEHAVIOUR          "MODE"
/*=========================================================================*/

/*=========================================================================*/
// == Global DEFINES == //
/*=========================================================================*/
  
  // App Details
  //------------
  #define FIRMWARE_VERSION                        "v1.0"
  #define FIRMWARE_NAME                           "HumidiFire"
  #define BLE_DEV_NAME_PREFIX                     "HumidiFire-" // 16 char max

  // Pin Defines
  //-------------
  // NOTE: See BluefruitConfig.h for other pin definitions
  
  #define PIN_ONBOARD_LED                       13   // Built-in LED pin
  
  #define PIN_PIXELS_1                          12  // NeoPixel strip 1
  #define PIN_PIXELS_2                          11  // NeoPixel strip 1
  
  #define PIN_CS                                10  // output - Chip Select for SPI device, used by BLE module
  #define PIN_AMP_SHTDN                               10  // output - nSHUTDOWN pin on Audio Amplifier board
                                                //9
  #define PIN_FAN                               6   // output - PWM control MOSFET to Blower Fan
  #define PIN_MIST                              5   // output - MOSFET to Mister / Bubbler Relay - do NOT PWM control
                                                //I2C-SCL
                                                //I2C-SDA
                                                
  #define PIN_CURRENT_MONITOR                   A0  // Analog Current Monitor, readout = 1A / V
                                                //A1
                                                //A2
                                                //A3
                                                //A4
  #define PIN_ENCODER_SW                        A5   // Encoder Switch, active LOW, no interrupt
                                                //SCK
                                                //MOSI
                                                //MISO
  #define PIN_ENCODER_A                         0  // RX0, interrupt driven
  #define PIN_ENCODER_B                         1  // TX1, interrupt driven


  // I2C Expander Pin Defines
  // https://github.com/adafruit/Adafruit-MCP23017-Arduino-Library#Pin-Addressing
  //-------------
  #define PIN_I2C_FX_RST                        0   // GPA0, Pin 21 on MCP23017
  #define PIN_I2C_FX_T00                        1   // GPA1, Pin 22 on MCP23017
  #define PIN_I2C_FX_T01                        2   // GPA2, Pin 23 on MCP23017
  #define PIN_I2C_FX_T02                        3   // GPA3, Pin 24 on MCP23017
  #define PIN_I2C_FX_T03                        4   // GPA4, Pin 25 on MCP23017
  #define PIN_I2C_FX_T04                        5   // GPA5, Pin 26 on MCP23017
  #define PIN_I2C_FX_T05                        6   // GPA6, Pin 27 on MCP23017
  #define PIN_I2C_FX_T06                        7   // GPA7, Pin 28 on MCP23017
  #define PIN_I2C_FX_T07                        15  // GPB7, Pin 8 on MCP23017
  #define PIN_I2C_FX_T08                        14  // GPB6, Pin 7 on MCP23017
  #define PIN_I2C_FX_T09                        13  // GPB5, Pin 6 on MCP23017
  #define PIN_I2C_FX_T10                        12  // GPB4, Pin 5 on MCP23017
  #define PIN_I2C_FX_VLP                        11  // GPB3, Pin 4 on MCP23017
  #define PIN_I2C_FX_VLN                        10  // GPB2, Pin 3 on MCP23017
  //#define PIN_I2C_                               9  // GPB1, Pin 2 on MCP23017
  //#define PIN_I2C_                               8  // GPB0, Pin 1 on MCP23017
      
  #define DISABLE                               HIGH
  #define ENABLE                                LOW

  
  // Bluefruit Connect App Buttons
  // - Numerical designators of buttons in the Control Pad
  //-------------
  #define APP_BTN_1                             1   // 
  #define APP_BTN_2                             2   // 
  #define APP_BTN_3                             3   // 
  #define APP_BTN_4                             4   // 
  #define APP_BTN_UP                            5   // 
  #define APP_BTN_DOWN                          6   // 
  #define APP_BTN_LEFT                          7   // 
  #define APP_BTN_RIGHT                         8   // 
  
  
  // Serial Settings
  //-------------
  #define SERIAL_BAUD_RATE                      115200    // (bps)

  // PWM Settings
  //-------------

  #define PWM_DEFAULT                           1      // (0 - 255) default PWM duty cycle
  #define PWM_INCREMENT                         1        // (0 - 255) controller increments
  #define PWM_MAX                               255      // (0 - 255) Max PWM duty cycle allowed in software
  #define PWM_MIN                               0        // (0 - 255) Min PWM duty cycle allowed in software

  // EasyButton Settings
  //-------------
  #define BTN_HOLD_DURATION_MS                  2000    // duration for onPressedFor                 
  #define BTN_SEQ_NUM_CLICKS                    2       // number of clicks for onSequence
  #define BTN_SEQ_TIMEOUT_MS                    (BTN_SEQ_NUM_CLICKS*200)    // timeout window for onSequence

  // NeoPixel Settings
  //-------------
  #define NUM_PIXELS_1                            28      // Number of Pixels in a strip
  #define NUM_PIXELS_2                            28      // Number of Pixels in a strip

  #define LOW_WATER_CURRENT_THRESHOLD             1       // if current monitor reads below this threshold, device goes to LOW_WATER state


/*=========================================================================*/
// == Declare Global Variables == //
/*=========================================================================*/
  extern uint8_t packetbuffer[];          // the packet buffer for Bluetooth communication
  
  bool ledState = true;           // var to toggle onboard LED state

  bool muteState = false;         //true = mute, false = unmute;

/*
  enum Mode
  {
    OFF = -1,     // Sytem off, standby
    
    CAMPFIRE,     // Orange, Red, & Yellow; Crackling fire
    SEASHORE,     // Blue, Green, & White; Ocean waves
    TROPICS,       // Green, Yellow, White; Tropical Rainforest
    
    NUM_MODES    // Keep in LAST place - translates to the number of modes in the list (1-indexed)
    
  }; // END enum Modes
  
  // update modeToString() when adding a new Mode

  Mode currentMode;      // declare enum object
  Mode previousMode;
  */

  enum fsmStateEnum
  {
    OFF = -1,     // Sytem off, standby
    
    START_CAMPFIRE,     // start-up sequence before runtime state
    RUN_CAMPFIRE,       // Orange, Red, & Yellow; Crackling fire
    LOW_WATER,
    
    NUM_MODES    // Keep in LAST place - translates to the number of modes in the list (1-indexed)
    
  }; // END enum Modes

  fsmStateEnum fsmState;  //declare enum var

  byte fanPwm;         // PWM Duty Cycle 0 - 255
  //byte mistPwm;        // PWM Duty Cycle 0 - 255
  bool mistState;      // Mister Control Relay State  

  bool settingsUpdate;      // flag that settings have been changed by BLE or button control

  float currentMonitor;
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
  void loop()
  {
    //button.update();  // EasyButton: update() function must be called repeatedly only if onPressedFor functionality is being used and interrupt is enabled
    button.read(PIN_ENCODER_SW); // EasyButton: read() checks button for non-interrupt enabled pins


    // ---------------------------------------------------- //
    // -- Handle Incoming Bluetooth Control Pad Packets -- //
    // --------------------------------------------------- //

    // Check is ble is connected before trying to readPacket
    // otherwise, readPacket has to wait to timeout every loop before code can proceed
    if(ble.isConnected())
    {
      uint8_t len = readPacket(&ble, BLE_READPACKET_TIMEOUT);
    }

    // Bluefruit Control Pad Module Buttons
    // see https://learn.adafruit.com/bluefruit-le-connect?view=all#control-pad-8-11
    
    if (packetbuffer[1] == 'B') 
    {
      uint8_t buttnum = packetbuffer[2] - '0';
      boolean pressed = packetbuffer[3] - '0';
      //boolean released;

      // -- MODE CONTROL 1, 2, 3, 4 -- //
      
        if((buttnum == APP_BTN_1) && (pressed == 1))   //When '1' button is pressed
        {
          /*
          if(currentMode == CAMPFIRE)
          {
            currentMode = OFF;        // toggle mode on/off
          }
          else
          {
            currentMode = CAMPFIRE;        
          }
          */
          
        } // END '1' Button

      // -- END MODE CONTROL 1, 2, 3, 4 -- //
    
      
      // -- FAN CONTROL ^ v -- //
      
        if((buttnum == APP_BTN_UP) && (pressed == 1))   //When 'UP' button is pressed
        {
          //fanPwmPct += PWM_INCREMENT;
          //if(fanPwmPct > PWM_MAX){fanPwmPct = PWM_MAX;} //duty cycle selection cannot be allowed to increment beyond boundaries
        
          if((fanPwm + PWM_INCREMENT) >= PWM_MAX){fanPwm = PWM_MAX;} //duty cycle selection cannot be allowed to increment beyond boundaries
          else{fanPwm += PWM_INCREMENT;}
          
        } // END "Up" Button
        
        if((buttnum == APP_BTN_DOWN) && (pressed == 1))   //When 'DOWN' button is pressed
        {
          //fanPwmPct -= PWM_INCREMENT;
          //if(fanPwmPct < PWM_MIN){fanPwmPct = PWM_MIN;} //duty cycle selection cannot be allowed to increment beyond boundaries
          
          if((fanPwm - PWM_INCREMENT) <= PWM_MIN){fanPwm = PWM_MIN;} //duty cycle selection cannot be allowed to increment beyond boundaries
          else{fanPwm -= PWM_INCREMENT;}
                    
        } // END "Down" Button

      // -- END FAN CONTROL ^ v -- //


      // -- MIST CONTROL -- < > //
      
      // MIST no longer under PWM control!!
      /*
        if((buttnum == APP_BTN_RIGHT) && (pressed == 1))   //When 'RIGHT' button is pressed
        {
          //mistPwmPct += PWM_INCREMENT;
          //if(mistPwmPct > PWM_MAX){mistPwmPct = PWM_MAX;} //duty cycle selection cannot be allowed to increment beyond boundaries
          
          if((mistPwm + PWM_INCREMENT) >= PWM_MAX){mistPwm = PWM_MAX;} //duty cycle selection cannot be allowed to increment beyond boundaries
          else{mistPwm += PWM_INCREMENT;}
  
        } // END "Right" Button
        
        if((buttnum == APP_BTN_LEFT) && (pressed == 1))   //When 'LEFT' button is pressed
        {
          //mistPwmPct -= PWM_INCREMENT;
          //if(mistPwmPct < PWM_MIN){mistPwmPct = PWM_MIN;} //duty cycle selection cannot be allowed to increment beyond boundaries
         
          if((mistPwm - PWM_INCREMENT) <= PWM_MIN){mistPwm = PWM_MIN;} //duty cycle selection cannot be allowed to increment beyond boundaries
          else{mistPwm -= PWM_INCREMENT;}
                    
        }  // END "Left" Button
      */
      // -- END MIST CONTROL < > -- //
         
      
      // Whever a BLE Control Pad button is pressed, print updated values to the Control Pad UART display
      // Do this at the END of the button update routine
      if(pressed == 1)
      {
        settingsUpdate = true;      //handle in Update Displays
        
        /*
        //Toggle Blink Indicator LED
        digitalWrite(PIN_ONBOARD_LED, !ledState);
        delay(50);
        digitalWrite(PIN_ONBOARD_LED, ledState);
        
        // Update Control Pad Display  
        ble.println();  // Clear the previous 2 lines from the screen
        ble.println();  // Clear the previous 2 lines from the screen
        
        //ble.print("Scene:\t");
        //ble.print(scene);

        ble.print("Mode:\t");
        //ble.print(currentMode);
        ble.print(modeToString(currentMode));

        ble.println();
        
        ble.print("Fan :\t");
        //ble.print(int(fanPwmPct*100));
        ble.print(fanPwm);
        ble.print(" \t");

        ble.print("Mist:\t");
        //ble.print(int(mistPwmPct*100));
        ble.print(mistPwm);
        ble.print(" ");
        */
        
      } // End Update Control Pad Display UART
    
    } // END Handle Incoming Bluetooth Control Pad Packets 


    // ------------------------------- //
    // -- Handle Rotary Encoder Updates-- //
    // ------------------------------- //

    long encoderDelta = rotaryEncoder.read();

    if(encoderDelta != 0)       // encoder has moved
    {
      settingsUpdate = true;      //handle in Update Displays
      
      rotaryEncoder.write(0);   //reset encoder accumulator

      if(encoderDelta > 0)                                        // encoder moved in POSITIVE direction
      {
        //if((fanPwm + encoderDelta) >= PWM_MAX){fanPwm = PWM_MAX;} // do not go above PWM_MAX
        //else {fanPwm += encoderDelta;}                            // increase by encoderDelta

        // tap VOL+
        i2cExpander.digitalWrite(PIN_I2C_FX_VLP, LOW);
        delay(10);
        i2cExpander.digitalWrite(PIN_I2C_FX_VLP, HIGH);
        

        /*
        if(Serial)
        { 
          Serial.print("encoderDelta: ");
          Serial.println(encoderDelta);
          Serial.print("fanPwm: ");
          Serial.println(fanPwm);
          Serial.println();
        }
        */
      }
      
      if (encoderDelta < 0)                                  // encoder moved in NEGATIVE direction
      {
        //if((fanPwm + encoderDelta) <= PWM_MIN){fanPwm = PWM_MIN;} // do not go below PWM_MIN
        //else {fanPwm += encoderDelta;}                            // decrease by encoderDelta (add a negative)

         // tap VOL-
        i2cExpander.digitalWrite(PIN_I2C_FX_VLN, LOW);
        delay(10);
        i2cExpander.digitalWrite(PIN_I2C_FX_VLN, HIGH);
        
        /*
        if(Serial)
        { 
          Serial.print("encoderDelta: ");
          Serial.println(encoderDelta);
          Serial.print("fanPwm: ");
          Serial.println(fanPwm);
          Serial.println();
        }
        */
      }

      /*
      // If BLE is connected, update Control Pad Display
      if(ble.isConnected())
      {
        ble.println();  // Clear the previous 2 lines from the screen
        ble.println();  // Clear the previous 2 lines from the screen
    
        ble.print("Mode:\t");
        //ble.print(currentMode);
        ble.print(modeToString(currentMode));
    
        ble.println();
        
        ble.print("Fan :\t");
        ble.print(fanPwm);
        ble.print(" \t");
    
        ble.print("Mist:\t");
        ble.print(mistPwm);
        ble.print(" ");
        
      } // END ble.isConnected()
      */
      
    } // END Encoder has moved

    // END Handle Rotary Encoder Updates

    // ------------------------------- //
    // -- Finite Stsate Machine -- //
    // ------------------------------- // 

     switch(fsmState)
      {
        case START_CAMPFIRE:
                                      
          //light campfire sound effect ON
          i2cExpander.digitalWrite(PIN_I2C_FX_T01, ENABLE);
          
          pixels1.setBrightness(255);
          pixels2.setBrightness(255);

          //flash lights
          pixels2.clear();
          pixels2.setPixelColor((NUM_PIXELS_2)*.5, pixels2.Color(255, 255, 255));
          pixels2.setPixelColor((NUM_PIXELS_2*.5)+2, pixels2.Color(255, 255, 255));
          pixels2.setPixelColor((NUM_PIXELS_2*.5)-2, pixels2.Color(255, 255, 255));
          pixels2.show();

          delay(25);        //leave lights on for some time
          pixels2.clear();  //turn lights off
          pixels2.show();

          //after 2 sec, fire catch sound happens
          delay(1800);
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

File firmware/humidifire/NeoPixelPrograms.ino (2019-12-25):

/* Collection of NeoPixel animation and helper functions
 * Moved to seperate file to clean up setup{} section of main code file
 * 
 * Includes:
 *  - colorWipe
 *  - larsonScanner
 *  - rainbow
 *  - rainbowCycle
 *  - theaterChase
 *  - theaterChaseRainbow
 *  - Wheel
 *  - hsb2rgb
 *  - flame
 * 
 */

/*
// Fill the dots one after the other with a color
void colorWipe(uint32_t c, uint8_t wait) 
{
  for(uint16_t i=0; i<pixels.numPixels(); i++) {
      pixels.setPixelColor(i, c);
      pixels.show();
      delay(wait);
  }
} // END colorWipe()
*/

/*
int pos = 0, dir = 1; // Position, direction of "eye" for larson scanner animation
void larsonScanner(uint32_t c, uint8_t wait)
{
   int j;
   
   for(uint16_t i=0; i<pixels.numPixels()+5; i++) 
   {
      // Draw 5 pixelss centered on pos.  setPixelColor() will clip any
      // pixelss off the ends of the strip, we don't need to watch for that.
      pixels.setPixelColor(pos - 2, 0x003b85); // Dark red
      pixels.setPixelColor(pos - 1, 0x005ed2); // Medium red
      pixels.setPixelColor(pos , 0x00c0ff); // Center pixels is brightest
      pixels.setPixelColor(pos + 1, 0x005ed2); // Medium red
      pixels.setPixelColor(pos + 2, 0x003b85); // Dark red
         
      pixels.show();
      delay(wait);
     
      // Rather than being sneaky and erasing just the tail pixels,
      // it's easier to erase it all and draw a new one next time.
      for(j=-2; j<= 2; j++) pixels.setPixelColor(pos+j, 0);
     
      // Bounce off ends of strip
      pos += dir;
      if(pos < 0) 
      {
        pos = 1;
        dir = -dir;
      } 
      else if(pos >= pixels.numPixels()) 
      {
        pos = pixels.numPixels() - 2;
        dir = -dir;
      } 
   } 
 //colorWipe(pixels.Color(0, 0, 0), 20);
 
} // END larsonScanner()
*/

/*
void rainbow(uint8_t wait) 
{
  uint16_t i, j;

  for(j=0; j<256; j++) {
    for(i=0; i<pixels.numPixels(); i++) {
      pixels.setPixelColor(i, Wheel((i+j) & 255));
    }
    pixels.show();
    delay(wait);
  }
  
} // END rainbow()
*/

/*
// Slightly different, this makes the rainbow equally distributed throughout
void rainbowCycle(uint8_t wait) 
{
  uint16_t i, j;

  for(j=0; j<256*5; j++) { // 5 cycles of all colors on wheel
    for(i=0; i< pixels.numPixels(); i++) {
      pixels.setPixelColor(i, Wheel(((i * 256 / pixels.numPixels()) + j) & 255));
    }
    pixels.show();
    delay(wait);
  }
  
} // END rainbowCycle()
*/

/*
//Theatre-style crawling lights
void theaterChase(uint32_t c, uint8_t wait) 
{
  for (int j=0; j<10; j++) {  //do 10 cycles of chasing
    for (int q=0; q < 3; q++) {
      for (int i=0; i < pixels.numPixels(); i=i+3) {
        pixels.setPixelColor(i+q, c);    //turn every third pixels on
      }
      pixels.show();

      delay(wait);

      for (int i=0; i < pixels.numPixels(); i=i+3) {
        pixels.setPixelColor(i+q, 0);        //turn every third pixels off
      }
    }
  }
} // END theaterChase()
*/

/*
//Theatre-style crawling lights with rainbow effect
void theaterChaseRainbow(uint8_t wait) 
{
  for (int j=0; j < 256; j++) {     // cycle all 256 colors in the wheel
    for (int q=0; q < 3; q++) {
      for (int i=0; i < pixels.numPixels(); i=i+3) {
        pixels.setPixelColor(i+q, Wheel( (i+j) % 255));    //turn every third pixels on
      }
      pixels.show();

      delay(wait);

      for (int i=0; i < pixels.numPixels(); i=i+3) {
        pixels.setPixelColor(i+q, 0);        //turn every third pixels off
      }
    }
  }
} // END theaterChaseRainbow()
*/

/*
// Input a value 0 to 255 to get a color value.
// The colours are a transition r - g - b - back to r.
uint32_t Wheel(byte WheelPos) 
{
  WheelPos = 255 - WheelPos;
  if(WheelPos < 85) {
    return pixels.Color(255 - WheelPos * 3, 0, WheelPos * 3);
  }
  if(WheelPos < 170) {
    WheelPos -= 85;
    return pixels.Color(0, WheelPos * 3, 255 - WheelPos * 3);
  }
  WheelPos -= 170;
  return pixels.Color(WheelPos * 3, 255 - WheelPos * 3, 0);
  
} // END Wheel()
*/

/******************************************************************************
 hsb2rgb()
 Convert Hue, Saturation, Brightness to Red, Green, Blue values
 
 https://blog.adafruit.com/2012/03/14/constant-brightness-hsb-to-rgb-algorithm/
 
 * accepts hue, saturation and brightness values and outputs three 8-bit color
 * values in an array (color[])
 *
 * saturation (sat) and brightness (bright) are 8-bit values.
 *
 * hue (index) is a value between 0 and 767. hue values out of range are
 * rendered as 0.
 *
 *****************************************************************************/
//Use color names as index values for color[]
#define RED     1
#define GREEN   2
#define BLUE    3

//Hue Value Color Map from Adafruit
//https://blog.adafruit.com/2012/03/14/constant-brightness-hsb-to-rgb-algorithm/
#define RED_VAL   0
#define BLUE_VAL  512

//Initialize array to hold RED, GREEN, BLUE color values from hsb2rgb() routine
uint8_t color[3]; 

void hsb2rgb(uint16_t index, uint8_t sat, uint8_t bright, uint8_t color[3])
{
  uint16_t r_temp, g_temp, b_temp;
  uint8_t index_mod;
  uint8_t inverse_sat = (sat ^ 255);

  index = index % 768;
  index_mod = index % 256;

  if (index < 256)
  {
    r_temp = index_mod ^ 255;
    g_temp = index_mod;
    b_temp = 0;
  }

  else if (index < 512)
  {
    r_temp = 0;
    g_temp = index_mod ^ 255;
    b_temp = index_mod;
  }

  else if ( index < 768)
  {
    r_temp = index_mod;
    g_temp = 0;
    b_temp = index_mod ^ 255;
  }

  else
  {
    r_temp = 0;
    g_temp = 0;
    b_temp = 0;
  }

  r_temp = ((r_temp * sat) / 255) + inverse_sat;
  g_temp = ((g_temp * sat) / 255) + inverse_sat;
  b_temp = ((b_temp * sat) / 255) + inverse_sat;

  r_temp = (r_temp * bright) / 255;
  g_temp = (g_temp * bright) / 255;
  b_temp = (b_temp * bright) / 255;

  color[RED]  = (uint8_t)r_temp;
  color[GREEN]  = (uint8_t)g_temp;
  color[BLUE] = (uint8_t)b_temp;
  
} // END hsb2rgb()

void flame1()
{

  //int r = 200,  g = 160,  b = 40;     // Yellow flame
  int r = 226,  g = 121,  b = 35;     // Orange flame
  //int r = 158,  g = 8,    b = 148;    // Purple flame 
  //int r = 74,   g = 150,  b = 12;     // Green flame
  
  for(int x = 0; x < pixels1.numPixels(); x++)
  {
    int flicker = random(0,150);
    //int flicker = random(0,55);
    int r1 = r-flicker;
    int g1 = g-flicker;
    int b1 = b-flicker;
    if(g1<0) g1=0;
    if(r1<0) r1=0;
    if(b1<0) b1=0;
    pixels1.setPixelColor(x, r1, g1, b1);
    pixels1.show();
    
    //delay(random(0,15));
    delay(random(0,3));
  }
  
} // END flame1()
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

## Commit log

2019-11-03 * draft lid cut out tester
2019-11-06 * added Bill of Materials
2019-11-09 * added vent deflector and floor register to lid cut out
2019-11-09 * moved cross flow fan inlet slit back from the fan body edge
2019-11-09 * added 24V Power Supply datasheet
2019-11-10 * added BLE Connect capability * Fan control via BLE (PWM range is not linear to fan speed)
2019-11-10 * - Rotary Encoder fan speed control * - Bluefruit Connect App fan, mist, and mode control
2019-11-14 * - collected and syncronized display updates of BLE & Serial Montior for settings changes at the end of loop() with settingsUpdate flag * - added modeToString() function to print mode names * - adde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
2019-11-16 * Added I2C expander code, but it isn't working yet and the loop code is runnig very slowly now. Needs debugging!
2019-11-21 * - Added campfire wav file * - Updated NUM_PIXELS to 31 * - Moved to Feather 32u4 * - Feather M0 has NO EEPROM memory!! * - Feather M0 isn't compatible with <Adafruit_MCP23008.h> I2C Expander library
2019-11-28 - Upgraded to MCP23017 I2C 16 I/O Expander Library
2019-11-30 * - Added Current Monitor * - Upgraded to MCP23017 I2C 16 I/O Expander Library
2019-11-30 * updated lid plate for component placement in hole cut through bin lid
2019-11-30 * Updated zip tie holes for wider straps, made rectangular * moved fan, vent deflector, and floor vent back 0.5" * Corrected floor vent width * changed lid shelf corner radius to 2 cm
2019-12-01 * added speaker mount holes and moved AC Inlet alongside corss flow fan
2019-12-03 * updates to speaker grill, fan grill, ac inlet mounting holes
2019-12-04 * New shorter enclosure with 1/4" material * wall cut out for fan motor penetration * Fan mounted to base of enclosure * speakers on both sides, speaker profiles added for clearance
2019-12-04 * - Added Mister Relay control to Pin 5
2019-12-05 * Updated default PWM rate and step for Fan control
2019-12-05 * added PCB Floorplan
2019-12-07 * started PCB schematic
    [HUM-ASM-001-v0-1.sch]
2019-12-10 * added more footprints to library and parts to schematic
    [HUM-ASM-001-v0-1.sch]
2019-12-11 * finished building pcb library parts * added one of each part to schematic * added Power and Audio pages to schematic
    [HUM-ASM-001-v0-1.sch]
2019-12-13 * Updated rotary encoder pin connections for Bourns encoder. * Rotation is now Interrupt based * Button press is now polling based
2019-12-14 * Added control for Amp Shutdown pin
2019-12-14 * Major progress on schematic
    [HUM-ASM-001-v0-1.sch]
2019-12-14 * schematic complete
    [HUM-ASM-001.sch]
2019-12-14 * PCB component placement complete
    [HUM-ASM-001.brd]
2019-12-14 * Removed unneeded components (Breakout connectors and Jumpers) * Laid 5V and GND planes
    [HUM-ASM-001.brd, HUM-ASM-001.sch]
2019-12-15 * pre-routed PCB
    [HUM-ASM-001.brd]
2019-12-15 * PCB 48V side routed
    [HUM-ASM-001.brd]
2019-12-15 * PCB Route complete
    [HUM-ASM-001.brd]
2019-12-16 * Fixed crash / recovery inconsistency * Pre silk screen clean up
    [HUM-ASM-001-before-crash.brd, HUM-ASM-001-recover.brd, HUM-ASM-001.brd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]
2019-12-16 * Normalized Text for Names and Values
    [HUM-ASM-001.brd, HUM-ASM-001.sch]
2019-12-16 * PCB Silk cleanup completed
    [HUM-ASM-001.brd, HUM-ASM-001.sch]
2019-12-16 * Final PCB v1.0 edits * Exported Gerber files and send to fab
    [HUM-ASM-001.brd, HUM-ASM-001.sch]
2019-12-16 * cleaned up folder * added PCB CAD image
    [HUM-ASM-001-before-crash.brd, HUM-ASM-001-recover.brd]
2019-12-16 * corrected PCBway Gerber rejection * unchecked "Negative Image" for Soldermask layers in Eagle CAM processor
2019-12-18 * renamed Gerber versions
2019-12-18 * added PCB render to enclosure design * added PCB standoff markers * flipped fan motor side panel cutout so laser cut burns will be hidden inside enclosure * added Encoder panel mount cut outs and s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
2019-12-19 * New enclosure version * Fan Filter Grill * LED cable cutouts * Outlines made into guides
2019-12-19 * added press-fit fan filter spacers * added speaker spacer and backer supports
2019-12-19 * tightened up Fan Filter Grill spacer press-fit
2019-12-19 * Updated Encoder Backing support and Spacer * Added cut holes for PCB standoffs (for option to use screws)
2019-12-19 * positioning adjustments after testing prototype * Major updates to lid shelf * updated enclosure box for hinged lid
2019-12-20 * another round of minor enclosure and lid improvements based on last cut and test * Back mist visor elongated to become leg for bottom of lid
2019-12-21 * Moved to 3 visor approach with LEDs in Front and Mid * added vapor exhaust vent hole patterns * re-added LED cable pass through cut outs * added bottle holder designs
2019-12-21 * raised jug support 1" to keep water line at 2.7" for float switch
2019-12-21 * updated size of hinge cut outs
2019-12-22 * Added Faux Rock Stencils * Added Mister wire passthrough Shelf Lid * Back Visor now has squared corners * Minor updates to Jug Spinte Support * Narrowed Bottle holder slots for tighter fit
2019-12-22 * Added cut lines to allow space to grip filter for removal
2019-12-23 * widened Bottle Holder hole * added pry-open slots to box sides
2019-12-23 * Updated Pinouts to reflect PCB wiring changes
2019-12-25 * pre-FSM model * now running 2 strips of LEDs * Sound & Volume control not tested / confirmed
2019-12-25 * v1.0 - finite state machine model * added LOW_WATER monitor state * finalized LED scene, fan speed, and start up sequence
